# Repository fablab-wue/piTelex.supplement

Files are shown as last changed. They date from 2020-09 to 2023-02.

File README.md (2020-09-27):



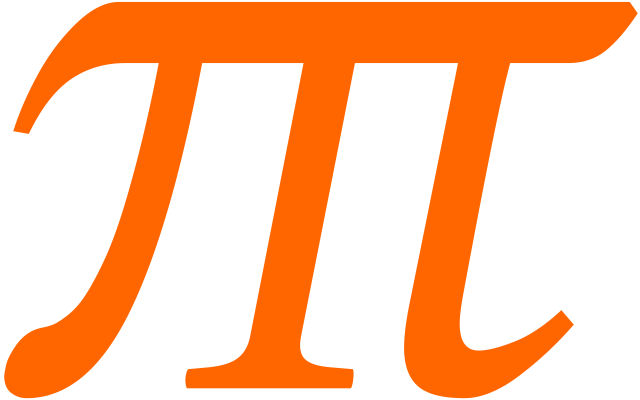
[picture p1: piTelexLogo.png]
# - piTelex.supplement



This project hold the additional files for the teletype project [piTelex](https://github.com/fablab-wue/piTelex)

**[For more informations see the WIKI pages](https://github.com/fablab-wue/piTelex/wiki)**

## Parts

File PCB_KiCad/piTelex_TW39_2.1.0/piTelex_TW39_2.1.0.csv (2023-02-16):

Source: | C:\KiCad\yyy\yyy.kicad_sch
Date: | 13/12/2022 18:44:19
Tool: | Eeschema (6.0.9)
Generator: | C:\Program Files\KiCad\6.0\bin\scripting\plugins/bom_csv_grouped_by_value.py
Component Count: | 58
Individual Components:
Item | Qty | Reference(s) | Value | LibPart | Footprint | Datasheet
 |  | C1 | 100n | Device:C | Capacitor_SMD:C_0805_2012Metric_Pad1.18x1.45mm_HandSolder | ~
 |  | C2 | 100n | Device:C | Capacitor_SMD:C_0805_2012Metric_Pad1.18x1.45mm_HandSolder | ~
 |  | C3 | * | Device:C | Capacitor_THT:C_Rect_L9.0mm_W4.2mm_P7.50mm_MKT | ~
 |  | C4 | 100n X2 275...305V~ | Device:C | Capacitor_THT:C_Rect_L16.5mm_W6.0mm_P15.00mm_MKT | ~
 |  | C5 | 100n | Device:C | Capacitor_SMD:C_0805_2012Metric_Pad1.18x1.45mm_HandSolder | ~
 |  | C6 | 100n | Device:C | Capacitor_SMD:C_0805_2012Metric_Pad1.18x1.45mm_HandSolder | ~
 |  | C7 | 100n | Device:C | Capacitor_SMD:C_0805_2012Metric_Pad1.18x1.45mm_HandSolder | ~
 |  | C8 | C_Polarized | Device:C_Polarized | Capacitor_Tantalum_SMD:CP_EIA-7343-31_Kemet-D_Pad2.25x2.55mm_HandSolder | ~
 |  | C9 | 100n | Device:C | Capacitor_SMD:C_0805_2012Metric_Pad1.18x1.45mm_HandSolder | ~
 |  | C10 | 100n | Device:C | Capacitor_SMD:C_0805_2012Metric_Pad1.18x1.45mm_HandSolder | ~
 |  | C11 | 100n | Device:C | Capacitor_SMD:C_0805_2012Metric_Pad1.18x1.45mm_HandSolder | ~
 |  | C12 | 100n | Device:C | Capacitor_SMD:C_0805_2012Metric_Pad1.18x1.45mm_HandSolder | ~
 |  | C13 | 100n | Device:C | Capacitor_SMD:C_0805_2012Metric_Pad1.18x1.45mm_HandSolder | ~
 |  | D1 | B250C1500G | Diode_Bridge:B250C1500G | Diode_THT:Diode_Bridge_Round_D9.8mm | https://www.vishay.com/docs/88501/b40c1500g.pdf
 |  | D2 | 1N4007 | Diode:1N4007 | Diode_THT:D_T-1_P2.54mm_Vertical_KathodeUp | http://www.vishay.com/docs/88503/1n4001.pdf
 |  | D3 | 1N4007 | Diode:1N4007 | Diode_THT:D_T-1_P2.54mm_Vertical_KathodeUp | http://www.vishay.com/docs/88503/1n4001.pdf
 |  | H1 | MountingHole_Pad | Mechanical:MountingHole_Pad | MountingHole:MountingHole_2.7mm_M2.5_ISO7380_Pad | ~
 |  | H2 | MountingHole_Pad | Mechanical:MountingHole_Pad | MountingHole:MountingHole_2.7mm_M2.5_ISO7380_Pad | ~
 |  | H3 | MountingHole_Pad | Mechanical:MountingHole_Pad | MountingHole:MountingHole_2.7mm_M2.5_ISO7380_Pad | ~
 |  | H4 | MountingHole_Pad | Mechanical:MountingHole_Pad | MountingHole:MountingHole_2.7mm_M2.5_ISO7380_Pad | ~
 |  | J1 | Screw_Terminal_01x02 | Connector:Screw_Terminal_01x02 | Connector_Molex:Molex_KK-254_AE-6410-02A_1x02_P2.54mm_Vertical | ~
 |  | J2 | Screw_Terminal_01x02 | Connector:Screw_Terminal_01x02 | Connector_Molex:Molex_KK-254_AE-6410-02A_1x02_P2.54mm_Vertical | ~
 |  | J3 | Raspberry_Pi_2_3 | Connector:Raspberry_Pi_2_3 | Connector_PinHeader_2.54mm:PinHeader_2x20_P2.54mm_Vertical | https://www.raspberrypi.org/documentation/hardware/raspberrypi/schematics/rpi_SCH_3bplus_1p0_reduced.pdf
 |  | J4 | Screw_Terminal_01x04 | Connector:Screw_Terminal_01x04 | Connector_Molex:Molex_KK-254_AE-6410-04A_1x04_P2.54mm_Vertical | ~
 |  | J5 | Screw_Terminal_01x02 | Connector:Screw_Terminal_01x02 | Connector_Molex:Molex_KK-254_AE-6410-02A_1x02_P2.54mm_Vertical | ~
 |  | J6 | Screw_Terminal_01x03 | Connector:Screw_Terminal_01x03 | Connector_Molex:Molex_KK-254_AE-6410-03A_1x03_P2.54mm_Vertical | ~
 |  | J7 | Screw_Terminal_01x05 | Connector:Screw_Terminal_01x05 | Connector_Molex:Molex_KK-254_AE-6410-05A_1x05_P2.54mm_Vertical | ~
 |  | J8 | Screw_Terminal_01x03 | Connector:Screw_Terminal_01x03 | Connector_Molex:Molex_KK-254_AE-6410-03A_1x03_P2.54mm_Vertical | ~
 |  | J9 | Screw_Terminal_01x02 | Connector:Screw_Terminal_01x02 | Connector_Molex:Molex_KK-254_AE-6410-02A_1x02_P2.54mm_Vertical | ~
 |  | J10 | Screw_Terminal_01x05 | Connector:Screw_Terminal_01x05 | Connector_Molex:Molex_KK-254_AE-6410-05A_1x05_P2.54mm_Vertical | ~
 |  | J11 | Screw_Terminal_01x04 | Connector:Screw_Terminal_01x04 | Connector_Molex:Molex_KK-254_AE-6410-04A_1x04_P2.54mm_Vertical | ~
 |  | J12 | Conn_01x03_Male | Connector:Conn_01x03_Male | Connector_PinHeader_2.54mm:PinHeader_1x03_P2.54mm_Vertical | ~
 |  | Q1 | BC338 | Transistor_BJT:BC338 | Package_TO_SOT_THT:TO-92_Inline | http://diotec.com/tl_files/diotec/files/pdf/datasheets/bc337
 |  | Q2 | BC338 | Transistor_BJT:BC338 | Package_TO_SOT_THT:TO-92_Inline | http://diotec.com/tl_files/diotec/files/pdf/datasheets/bc337
 |  | R1 | 68R | Device:R | Resistor_SMD:R_0805_2012Metric_Pad1.20x1.40mm_HandSolder | ~
 |  | R2 | 68R | Device:R | Resistor_SMD:R_0805_2012Metric_Pad1.20x1.40mm_HandSolder | ~
 |  | R3 | 330 | Device:R | Resistor_SMD:R_0805_2012Metric_Pad1.20x1.40mm_HandSolder | ~
 |  | R4 | 330 | Device:R | Resistor_SMD:R_0805_2012Metric_Pad1.20x1.40mm_HandSolder | ~
 |  | R5 | 330 | Device:R | Resistor_SMD:R_0805_2012Metric_Pad1.20x1.40mm_HandSolder | ~
 |  | R6 | 330 | Device:R | Resistor_SMD:R_0805_2012Metric_Pad1.20x1.40mm_HandSolder | ~
 |  | R7 | 330 | Device:R | Resistor_SMD:R_0805_2012Metric_Pad1.20x1.40mm_HandSolder | ~
 |  | R8 | 330 | Device:R | Resistor_SMD:R_0805_2012Metric_Pad1.20x1.40mm_HandSolder | ~
 |  | R9 | 1k | Device:R | Resistor_SMD:R_0805_2012Metric_Pad1.20x1.40mm_HandSolder | ~
 |  | R10 | 1k | Device:R | Resistor_SMD:R_0805_2012Metric_Pad1.20x1.40mm_HandSolder | ~
 |  | R11 | 1k | Device:R | Resistor_SMD:R_0805_2012Metric_Pad1.20x1.40mm_HandSolder | ~
 |  | R12 | 1k | Device:R | Resistor_SMD:R_0805_2012Metric_Pad1.20x1.40mm_HandSolder | ~
 |  | R13 | 3K3 | Device:R | Resistor_SMD:R_0805_2012Metric_Pad1.20x1.40mm_HandSolder | ~
 |  | R14 | 3K3 | Device:R | Resistor_SMD:R_0805_2012Metric_Pad1.20x1.40mm_HandSolder | ~
 |  | R15 | 3K3 | Device:R | Resistor_SMD:R_0805_2012Metric_Pad1.20x1.40mm_HandSolder | ~
 |  | R16 | 3K3 | Device:R | Resistor_SMD:R_0805_2012Metric_Pad1.20x1.40mm_HandSolder | ~
 |  | R17 | 3K3 | Device:R | Resistor_SMD:R_0805_2012Metric_Pad1.20x1.40mm_HandSolder | ~
 |  | R18 | 3K3 | Device:R | Resistor_SMD:R_0805_2012Metric_Pad1.20x1.40mm_HandSolder | ~
 |  | U1 | PC817 | Isolator:PC817 | Package_DIP:DIP-4_W7.62mm | http://www.soselectronic.cz/a_info/resource/d/pc817.pdf
 |  | U2 | TLP627 | Isolator:TLP627 | Package_DIP:DIP-4_W7.62mm | https://toshiba.semicon-storage.com/info/docget.jsp?did=16914&prodName=TLP627
 |  | U3 | TLP627 | Isolator:TLP627 | Package_DIP:DIP-4_W7.62mm | https://toshiba.semicon-storage.com/info/docget.jsp?did=16914&prodName=TLP627
 |  | U4 | TLP627 | Isolator:TLP627 | Package_DIP:DIP-4_W7.62mm | https://toshiba.semicon-storage.com/info/docget.jsp?did=16914&prodName=TLP627
 |  | U5 | TLP627 | Isolator:TLP627 | Package_DIP:DIP-4_W7.62mm | https://toshiba.semicon-storage.com/info/docget.jsp?did=16914&prodName=TLP627
 |  | U6 | R-78C5.0-1.0 | Regulator_Switching:R-78C5.0-1.0 | Converter_DCDC:Converter_DCDC_RECOM_R-78E-0.5_THT | https://www.recom-power.com/pdf/Innoline/R-78Cxx-1.0.pdf
Collated Components:
Item | Qty | Reference(s) | Value | LibPart | Footprint | Datasheet
1 | 10 | C1, C2, C5, C6, C7, C9, C10, C11, C12, C13 | 100n | Device:C | Capacitor_SMD:C_0805_2012Metric_Pad1.18x1.45mm_HandSolder | ~
2 | 1 | C3 | * | Device:C | Capacitor_THT:C_Rect_L9.0mm_W4.2mm_P7.50mm_MKT | ~
3 | 1 | C4 | 100n X2 275...305V~ | Device:C | Capacitor_THT:C_Rect_L16.5mm_W6.0mm_P15.00mm_MKT | ~
4 | 1 | C8 | C_Polarized | Device:C_Polarized | Capacitor_Tantalum_SMD:CP_EIA-7343-31_Kemet-D_Pad2.25x2.55mm_HandSolder | ~
5 | 1 | D1 | B250C1500G | Diode_Bridge:B250C1500G | Diode_THT:Diode_Bridge_Round_D9.8mm | https://www.vishay.com/docs/88501/b40c1500g.pdf
6 | 2 | D2, D3 | 1N4007 | Diode:1N4007 | Diode_THT:D_T-1_P2.54mm_Vertical_KathodeUp | http://www.vishay.com/docs/88503/1n4001.pdf
7 | 4 | H1, H2, H3, H4 | MountingHole_Pad | Mechanical:MountingHole_Pad | MountingHole:MountingHole_2.7mm_M2.5_ISO7380_Pad | ~
8 | 4 | J1, J2, J5, J9 | Screw_Terminal_01x02 | Connector:Screw_Terminal_01x02 | Connector_Molex:Molex_KK-254_AE-6410-02A_1x02_P2.54mm_Vertical | ~
9 | 1 | J3 | Raspberry_Pi_2_3 | Connector:Raspberry_Pi_2_3 | Connector_PinHeader_2.54mm:PinHeader_2x20_P2.54mm_Vertical | https://www.raspberrypi.org/documentation/hardware/raspberrypi/schematics/rpi_SCH_3bplus_1p0_reduced.pdf
10 | 2 | J4, J11 | Screw_Terminal_01x04 | Connector:Screw_Terminal_01x04 | Connector_Molex:Molex_KK-254_AE-6410-04A_1x04_P2.54mm_Vertical | ~
11 | 2 | J6, J8 | Screw_Terminal_01x03 | Connector:Screw_Terminal_01x03 | Connector_Molex:Molex_KK-254_AE-6410-03A_1x03_P2.54mm_Vertical | ~
12 | 2 | J7, J10 | Screw_Terminal_01x05 | Connector:Screw_Terminal_01x05 | Connector_Molex:Molex_KK-254_AE-6410-05A_1x05_P2.54mm_Vertical | ~
13 | 1 | J12 | Conn_01x03_Male | Connector:Conn_01x03_Male | Connector_PinHeader_2.54mm:PinHeader_1x03_P2.54mm_Vertical | ~
14 | 2 | Q1, Q2 | BC338 | Transistor_BJT:BC338 | Package_TO_SOT_THT:TO-92_Inline | http://diotec.com/tl_files/diotec/files/pdf/datasheets/bc337
15 | 2 | R1, R2 | 68R | Device:R | Resistor_SMD:R_0805_2012Metric_Pad1.20x1.40mm_HandSolder | ~
16 | 6 | R3, R4, R5, R6, R7, R8 | 330 | Device:R | Resistor_SMD:R_0805_2012Metric_Pad1.20x1.40mm_HandSolder | ~
17 | 4 | R9, R10, R11, R12 | 1k | Device:R | Resistor_SMD:R_0805_2012Metric_Pad1.20x1.40mm_HandSolder | ~
18 | 6 | R13, R14, R15, R16, R17, R18 | 3K3 | Device:R | Resistor_SMD:R_0805_2012Metric_Pad1.20x1.40mm_HandSolder | ~
19 | 1 | U1 | PC817 | Isolator:PC817 | Package_DIP:DIP-4_W7.62mm | http://www.soselectronic.cz/a_info/resource/d/pc817.pdf
20 | 4 | U2, U3, U4, U5 | TLP627 | Isolator:TLP627 | Package_DIP:DIP-4_W7.62mm | https://toshiba.semicon-storage.com/info/docget.jsp?did=16914&prodName=TLP627
21 | 1 | U6 | R-78C5.0-1.0 | Regulator_Switching:R-78C5.0-1.0 | Converter_DCDC:Converter_DCDC_RECOM_R-78E-0.5_THT | https://www.recom-power.com/pdf/Innoline/R-78Cxx-1.0.pdf

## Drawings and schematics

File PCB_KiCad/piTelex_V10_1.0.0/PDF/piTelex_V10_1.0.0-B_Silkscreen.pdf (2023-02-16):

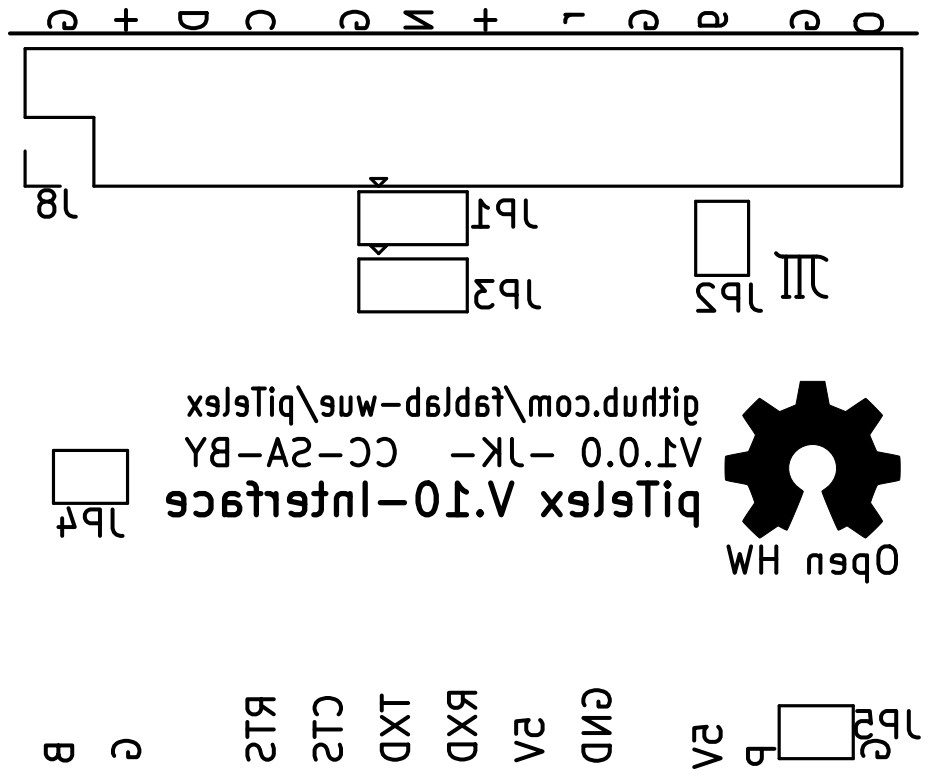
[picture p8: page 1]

G5V CC-SA-BY GNDG

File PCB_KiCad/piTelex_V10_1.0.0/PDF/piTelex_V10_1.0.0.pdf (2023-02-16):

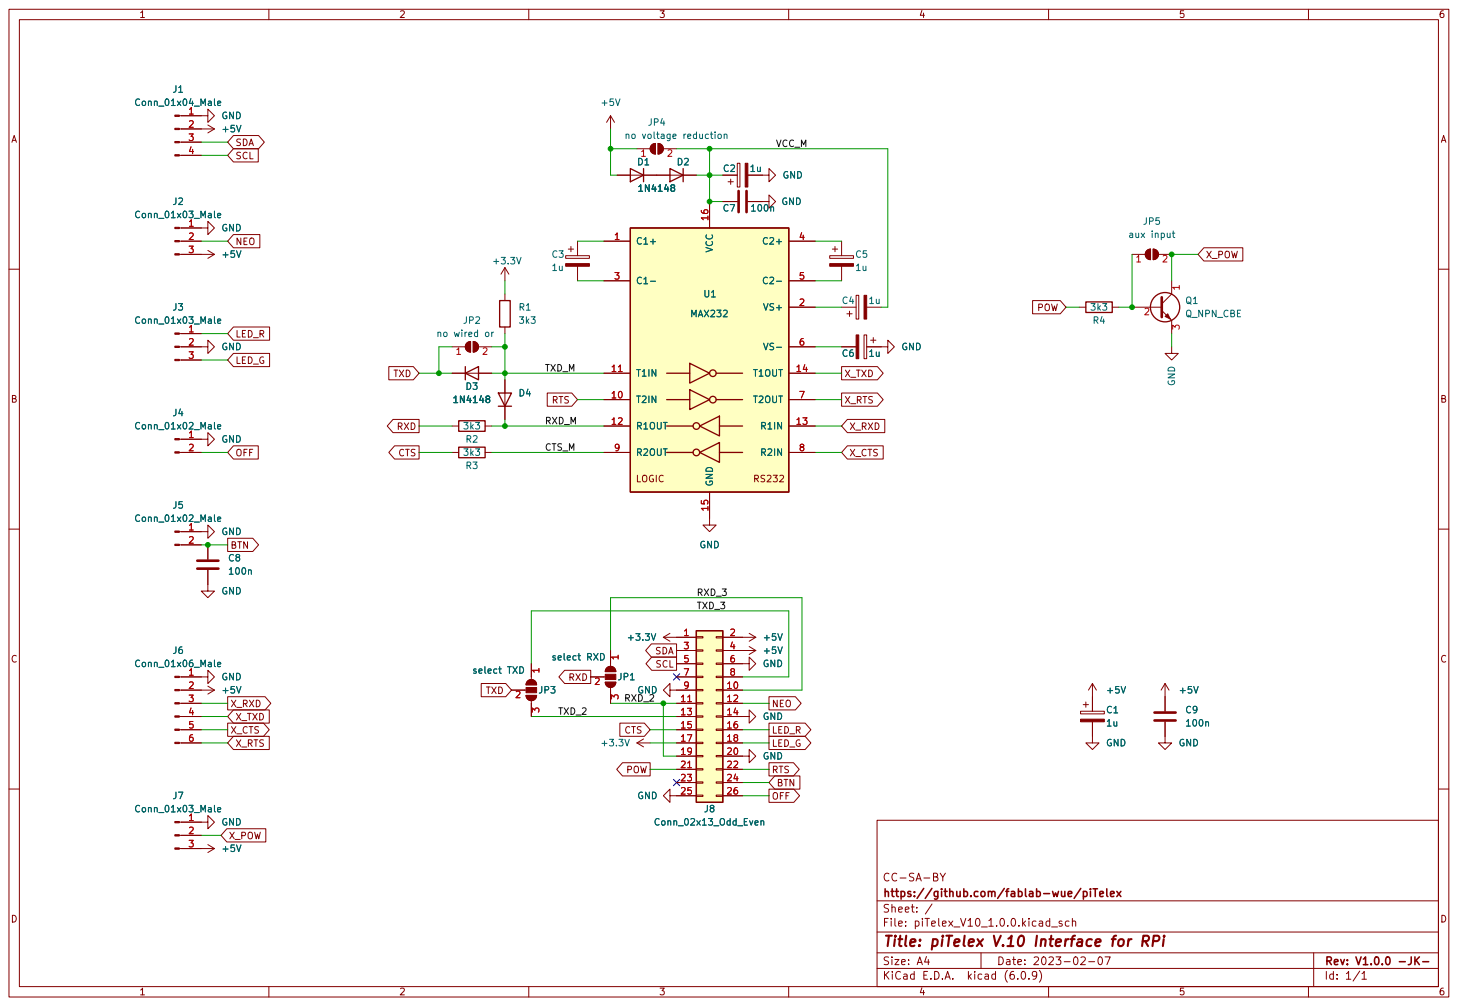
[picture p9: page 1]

aux input GND GND 1234

File: piTelex_V10_1.0.0.kicad_sch Sheet: / https://github.com/fablab-wue/piTelex CC-SA-BY

Id: 1/1 Title: piTelex V.10 Interface for RPi

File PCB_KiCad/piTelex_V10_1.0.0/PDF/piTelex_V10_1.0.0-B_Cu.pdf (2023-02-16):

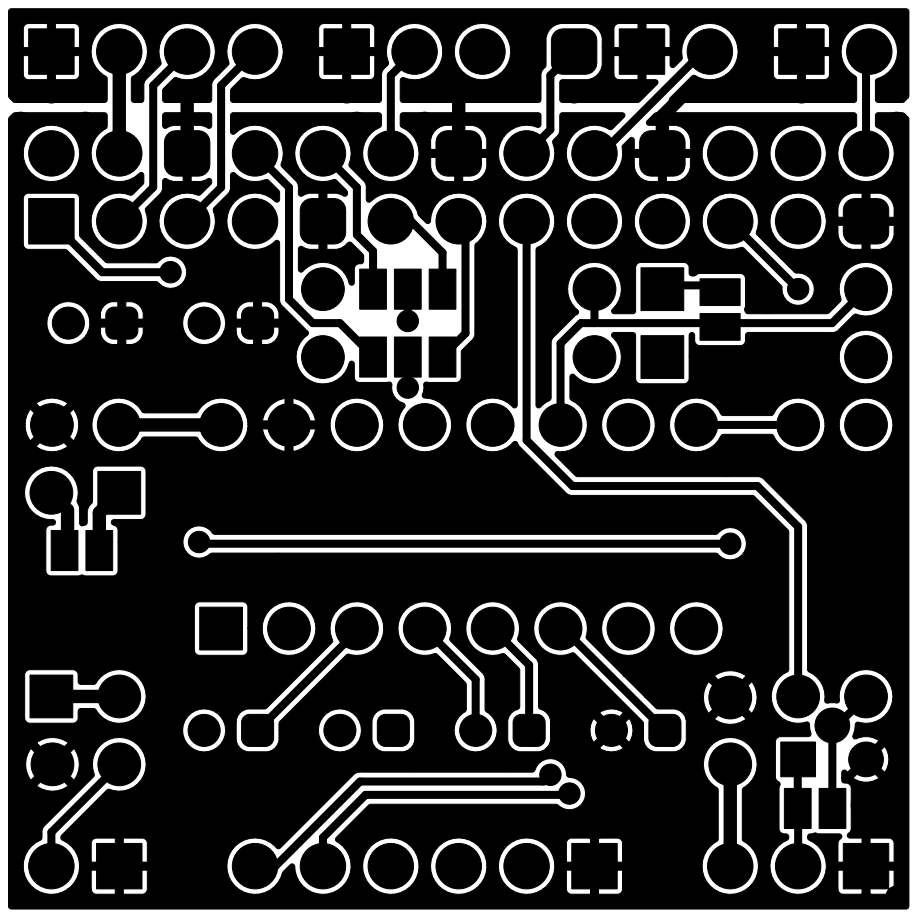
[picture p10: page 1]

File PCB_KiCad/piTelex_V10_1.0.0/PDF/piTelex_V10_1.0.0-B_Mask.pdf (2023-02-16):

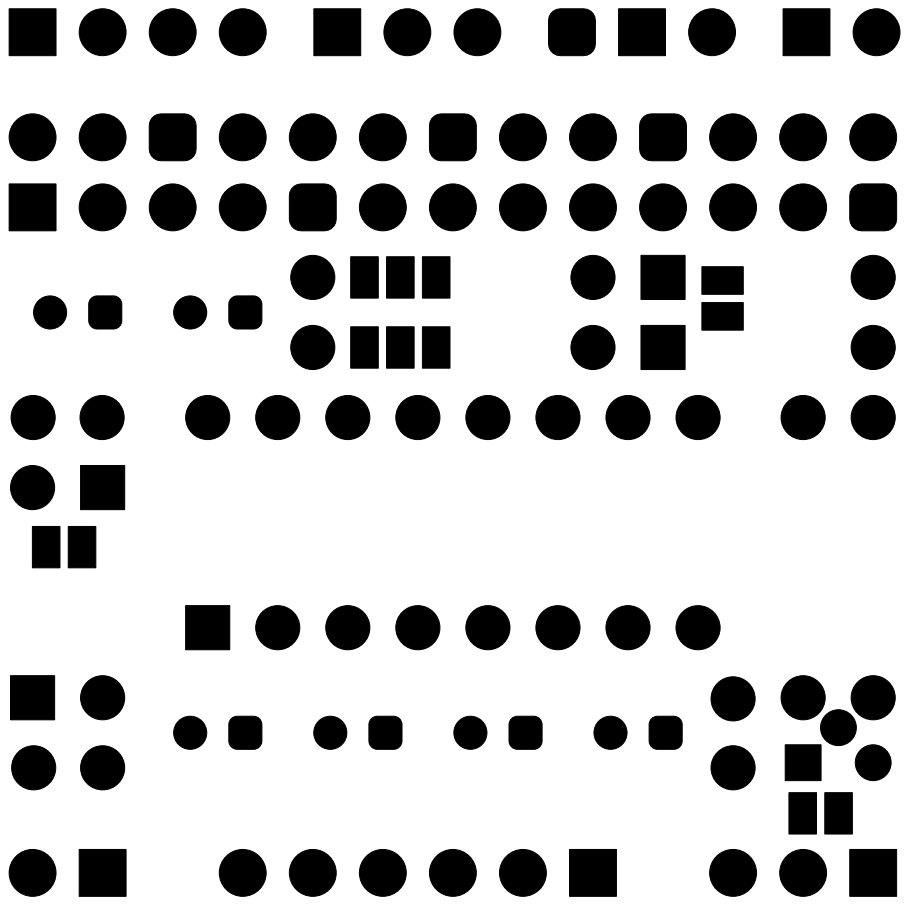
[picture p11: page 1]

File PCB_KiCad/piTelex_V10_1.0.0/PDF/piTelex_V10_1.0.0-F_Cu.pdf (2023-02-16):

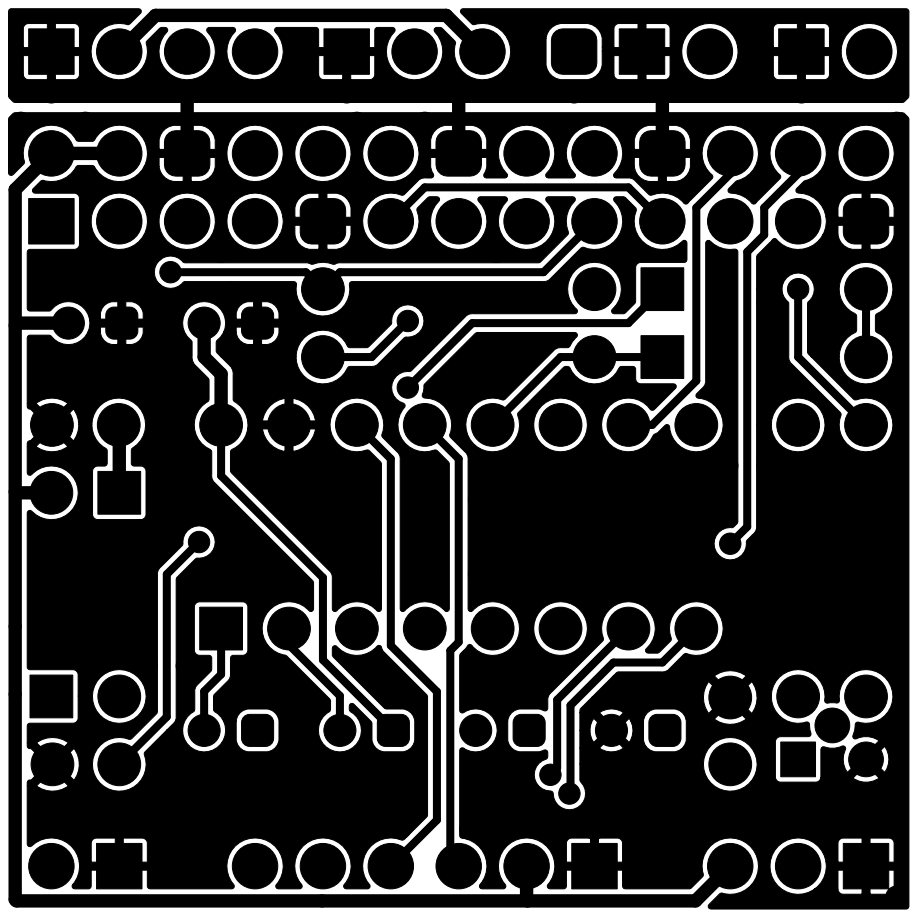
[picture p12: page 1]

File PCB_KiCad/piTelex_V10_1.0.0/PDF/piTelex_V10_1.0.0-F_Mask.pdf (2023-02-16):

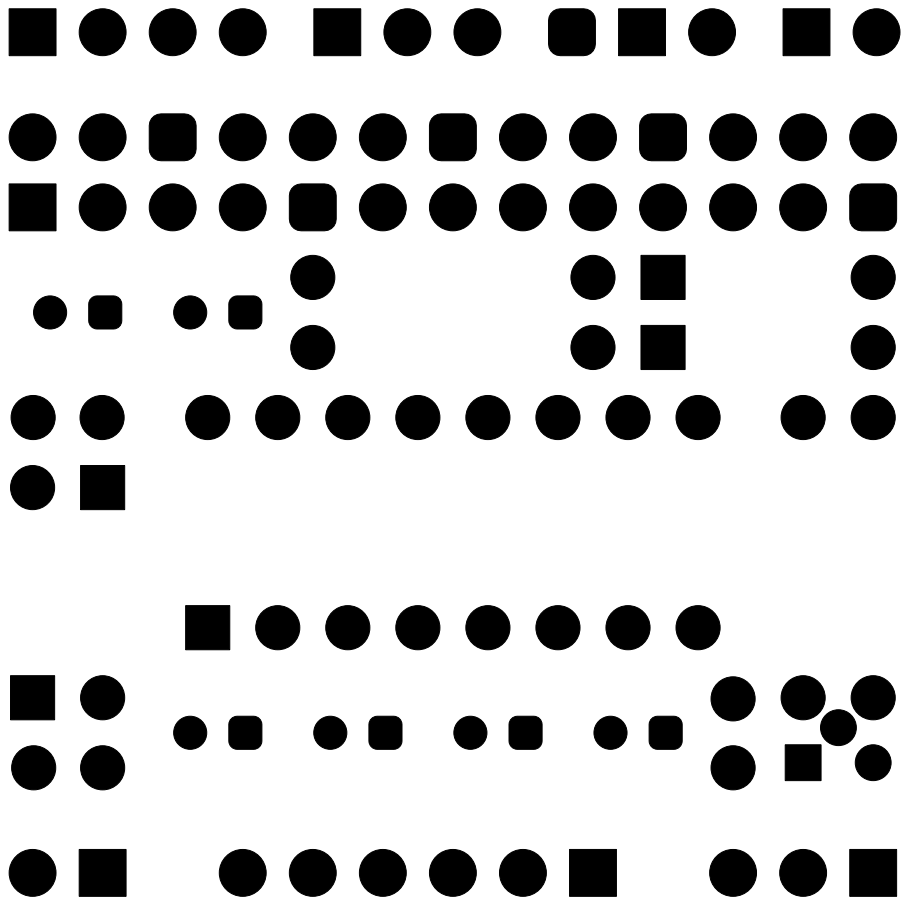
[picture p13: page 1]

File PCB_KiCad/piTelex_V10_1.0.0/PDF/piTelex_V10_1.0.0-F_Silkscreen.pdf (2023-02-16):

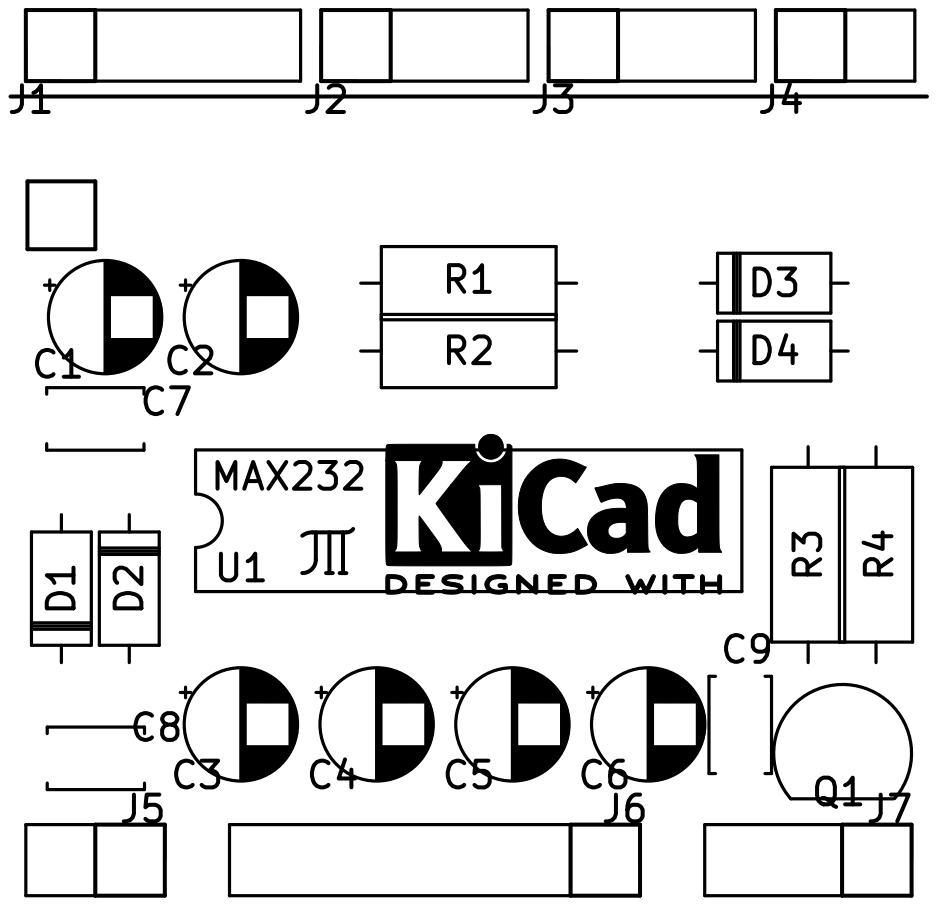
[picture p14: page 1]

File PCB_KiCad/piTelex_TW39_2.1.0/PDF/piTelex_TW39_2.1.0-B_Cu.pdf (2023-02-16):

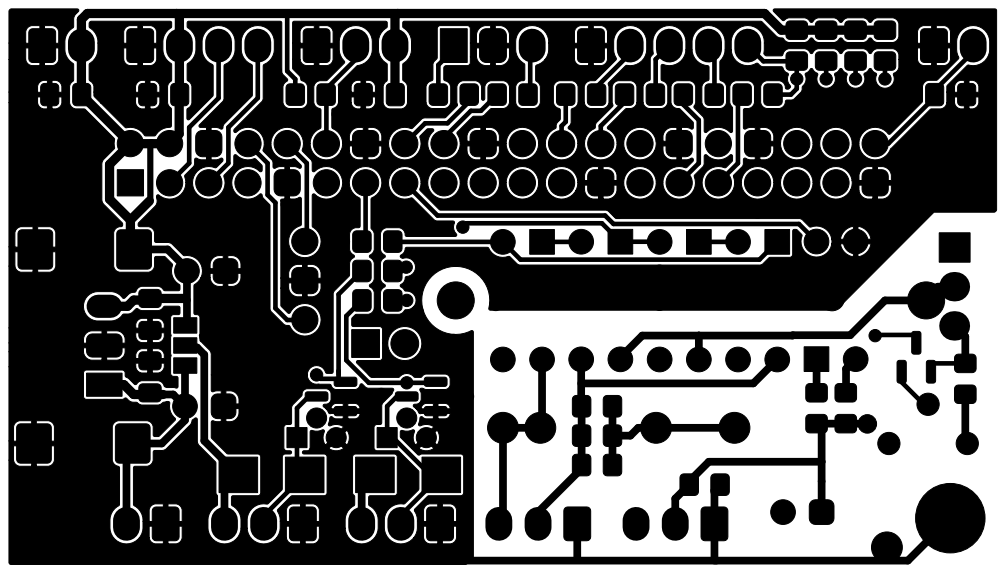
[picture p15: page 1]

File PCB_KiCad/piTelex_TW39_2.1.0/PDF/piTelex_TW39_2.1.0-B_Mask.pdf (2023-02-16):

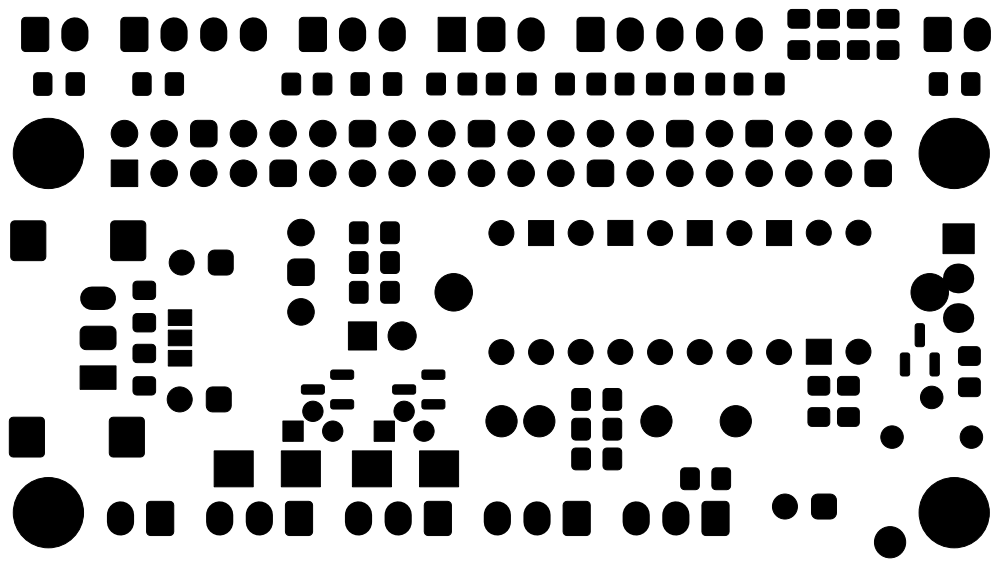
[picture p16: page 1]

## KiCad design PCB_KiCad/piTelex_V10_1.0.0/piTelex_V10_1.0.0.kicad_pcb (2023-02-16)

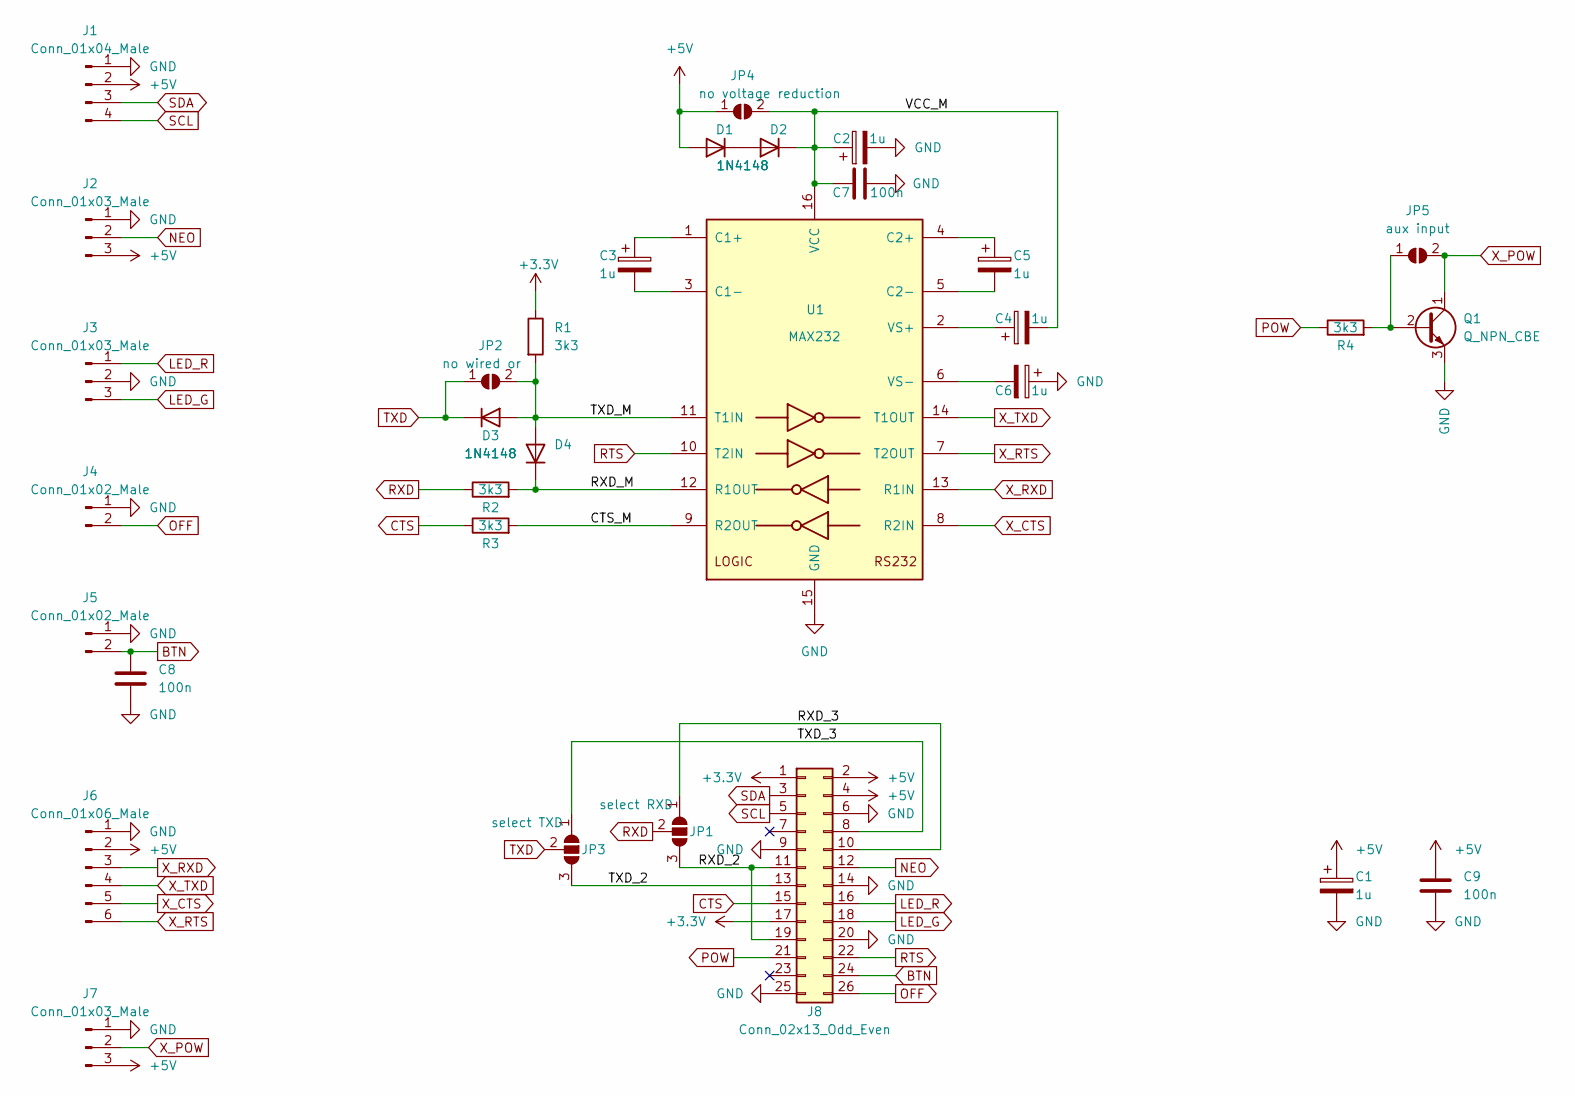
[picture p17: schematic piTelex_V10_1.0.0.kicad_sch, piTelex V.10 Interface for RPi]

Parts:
C1, C2, C3, C4, C5, C6: 1u; CP_Radial_D4.0mm_P2.00mm
C7, C8, C9: 100n; C_Disc_D3.4mm_W2.1mm_P2.50mm
D1, D2, D3, D4: 1N4148; D_DO-35_SOD27_P7.62mm_Horizontal
J1: Conn_01x04_Male; PinHeader_1x04_P2.54mm_Vertical
J2, J3, J7: Conn_01x03_Male; PinHeader_1x03_P2.54mm_Vertical
J4, J5: Conn_01x02_Male; PinHeader_1x02_P2.54mm_Vertical
J6: Conn_01x06_Male; PinHeader_1x06_P2.54mm_Vertical
J8: Conn_02x13_Odd_Even; PinSocket_2x13_P2.54mm_Vertical
JP1: select RXD; SolderJumper-3_P1.3mm_Open_Pad1.0x1.5mm
JP2: no wired or; SolderJumper-2_P1.3mm_Open_Pad1.0x1.5mm
JP3: select TXD; SolderJumper-3_P1.3mm_Open_Pad1.0x1.5mm
JP4: no voltage reduction; SolderJumper-2_P1.3mm_Open_Pad1.0x1.5mm
JP5: aux input; SolderJumper-2_P1.3mm_Open_Pad1.0x1.5mm
Q1: Q_NPN_CBE; TO-92L
R1, R2, R3, R4: 3k3; R_Axial_DIN0207_L6.3mm_D2.5mm_P10.16mm_Horizontal
U1: MAX232; DIP-16_W7.62mm

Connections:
+3.3V: J8.1, J8.17, R1.1
+5V: C1.1, C9.1, D1.2 (A), J1.2, J2.3, J6.2, J7.3, J8.2, J8.4, JP4.1 (A)
/CTS_M: R3.2, U1.9 (R2OUT)
/RXD_2: J8.11, J8.19, JP1.3 (B)
/RXD_3: J8.10, JP1.1 (A)
/RXD_M: D4.1 (K), R2.2, U1.12 (R1OUT)
/TXD_2: J8.13, JP3.3 (B)
/TXD_3: J8.8, JP3.1 (A)
/TXD_M: D3.2 (A), D4.2 (A), JP2.2 (B), R1.2, U1.11 (T1IN)
/VCC_M: C2.1, C4.2, C7.1, D2.1 (K), JP4.2 (B), U1.16 (VCC)
BTN: C8.1, J5.2, J8.24
CTS: J8.15, R3.1
GND: C1.2, C2.2, C6.1, C7.2, C8.2, C9.2, J1.1, J2.1, J3.2, J4.1, J5.1, J6.1, J7.1, J8.6, J8.9, J8.14, J8.20, J8.25, Q1.3 (E), U1.15 (GND)
LED_G: J3.3, J8.18
LED_R: J3.1, J8.16
NEO: J2.2, J8.12
unnamed: C3.1, U1.1 (C1+)
unnamed: C3.2, U1.3 (C1-)
unnamed: C4.1, U1.2 (VS+)
unnamed: C5.1, U1.4 (C2+)
unnamed: C5.2, U1.5 (C2-)
unnamed: C6.2, U1.6 (VS-)
unnamed: D1.1 (K), D2.2 (A)
unnamed: JP5.1 (A), Q1.2 (B), R4.2
OFF: J4.2, J8.26
POW: J8.21, R4.1
RTS: J8.22, U1.10 (T2IN)
RXD: JP1.2 (C), R2.1
SCL: J1.4, J8.5
SDA: J1.3, J8.3
TXD: D3.1 (K), JP2.1 (A), JP3.2 (C)
X_CTS: J6.5, U1.8 (R2IN)
X_POW: J7.2, JP5.2 (B), Q1.1 (C)
X_RTS: J6.6, U1.7 (T2OUT)
X_RXD: J6.3, U1.13 (R1IN)
X_TXD: J6.4, U1.14 (T1OUT)

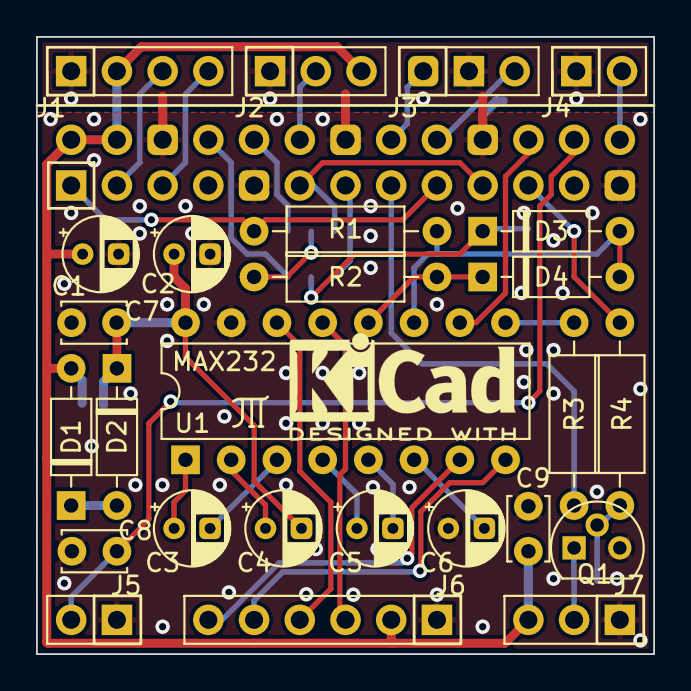
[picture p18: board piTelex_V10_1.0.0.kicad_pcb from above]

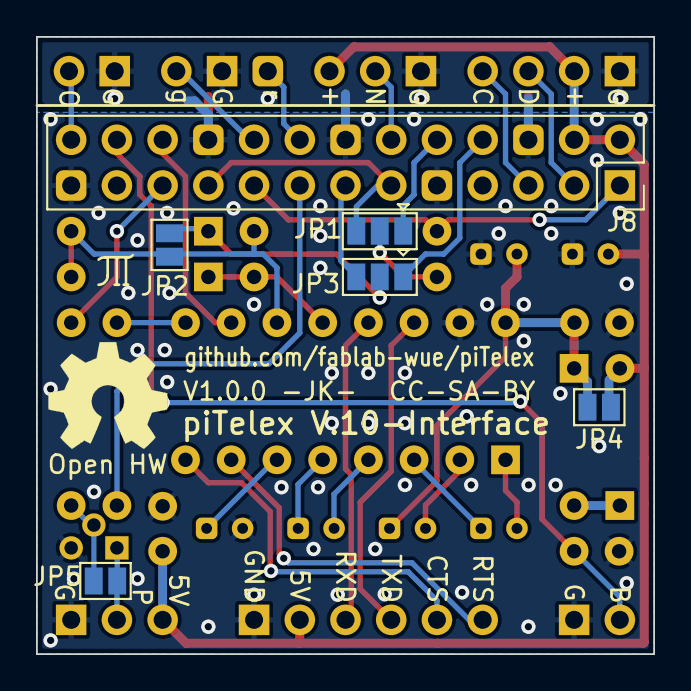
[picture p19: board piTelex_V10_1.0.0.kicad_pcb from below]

Board: 2 copper layers, 34.3 x 34.3 mm, 32 parts (6 on the bottom side), 36 nets.

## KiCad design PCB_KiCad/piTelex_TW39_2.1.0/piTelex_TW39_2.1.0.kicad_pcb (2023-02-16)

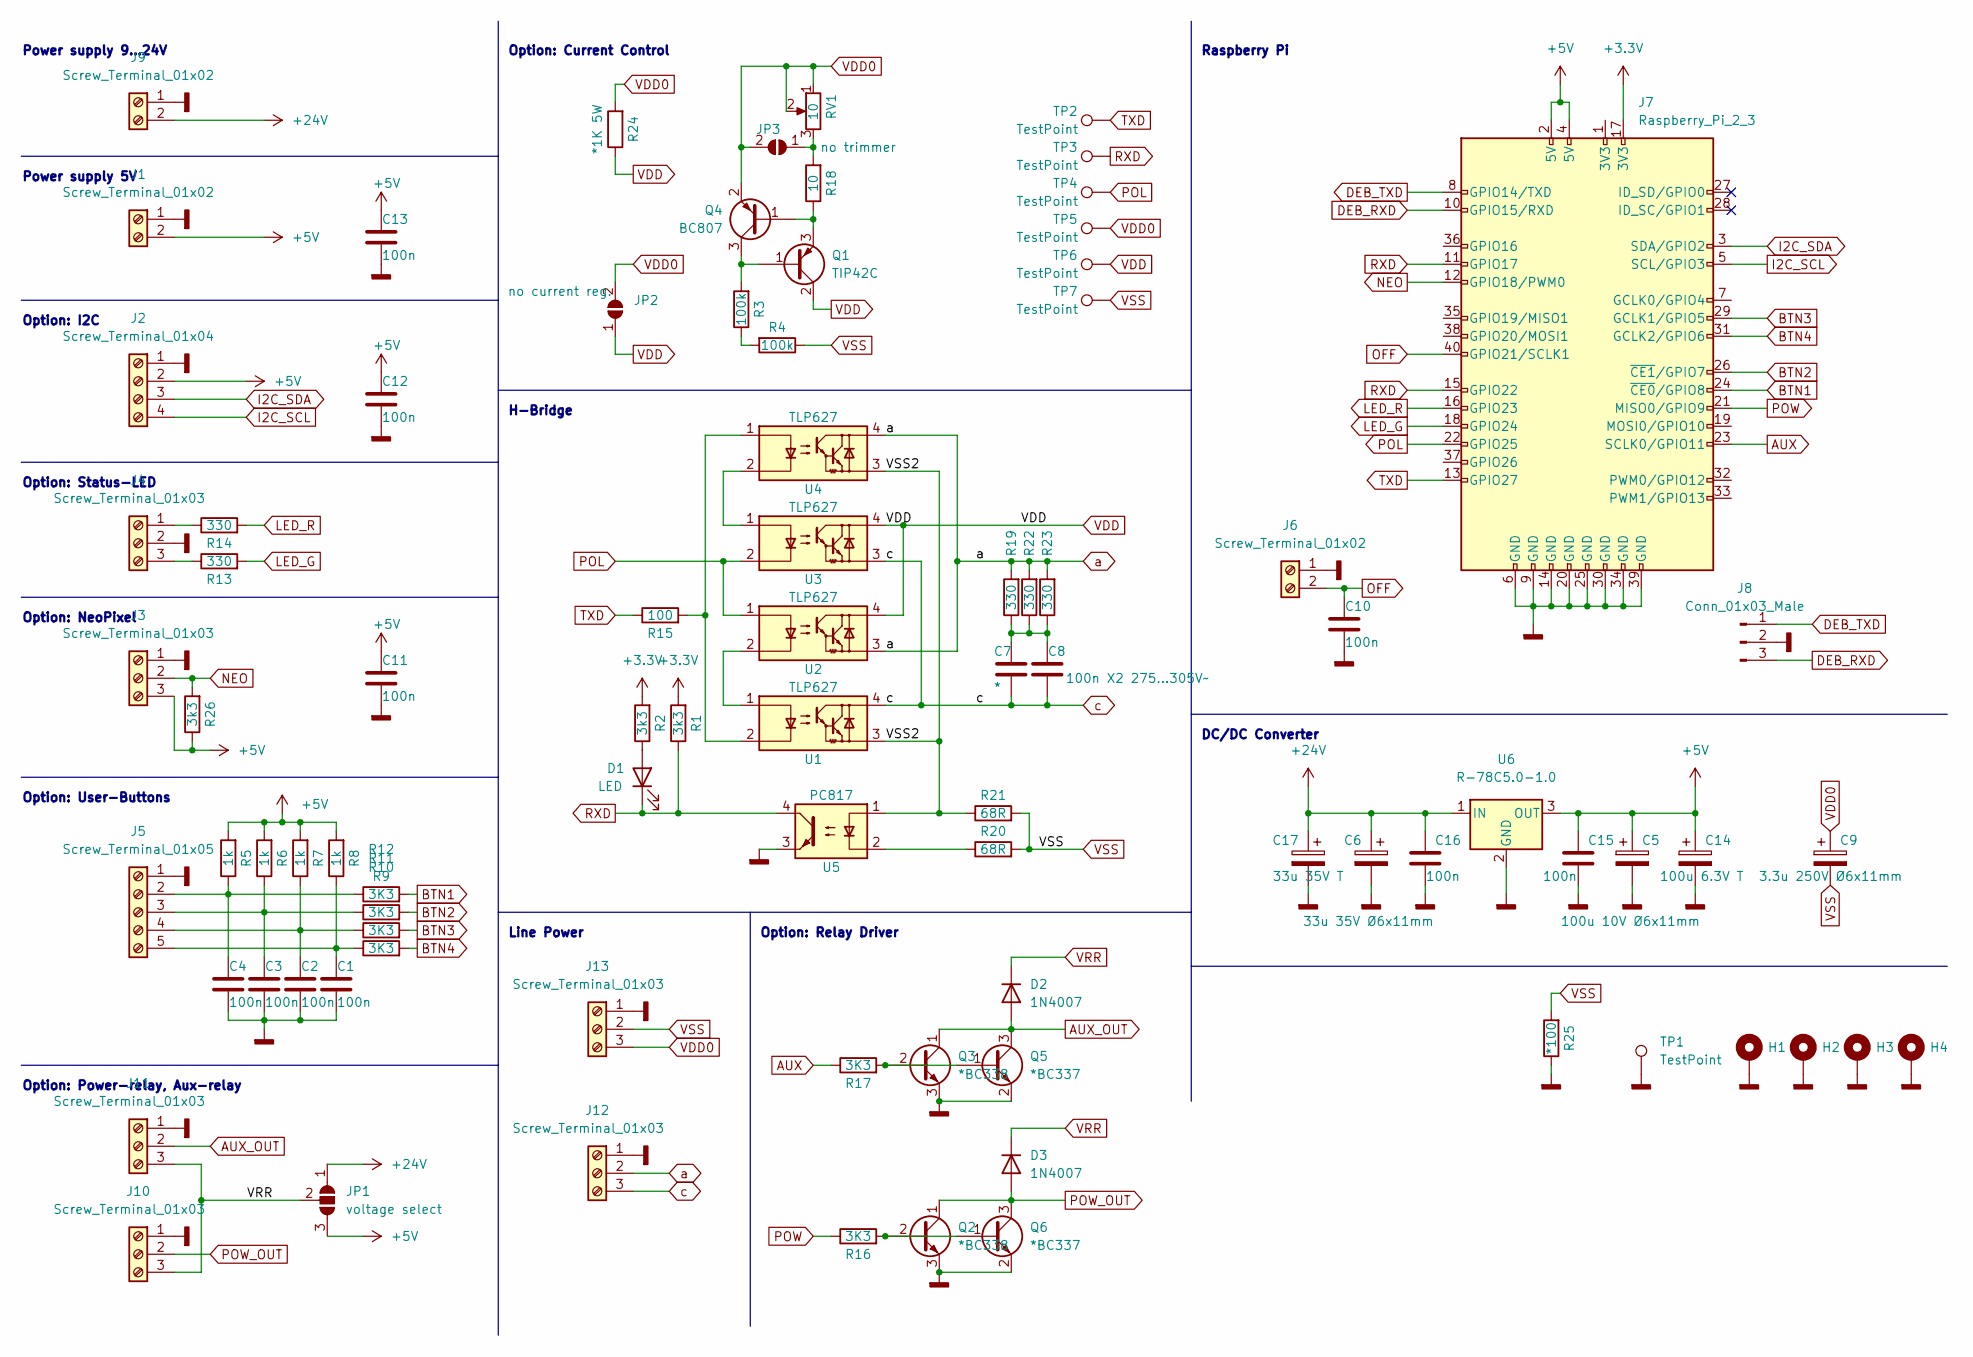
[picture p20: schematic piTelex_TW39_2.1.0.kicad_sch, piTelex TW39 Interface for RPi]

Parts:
C1, C2, C3, C4, C10, C11, C12, C13, C15, C16: 100n; C_0805_2012Metric_Pad1.18x1.45mm_HandSolder
C5: 100u 10V Ø6x11mm; CP_Radial_D7.5mm_P2.50mm
C6: 33u 35V Ø6x11mm; CP_Radial_D7.5mm_P2.50mm
C7: *; C_Rect_L9.0mm_W4.2mm_P7.50mm_MKT
C8: 100n X2 275...305V~; C_Rect_L16.5mm_W6.0mm_P15.00mm_MKT
C9: 3.3u 250V Ø6x11mm; CP_Radial_D7.5mm_P2.50mm
C14: 100u 6.3V T; CP_EIA-7343-31_Kemet-D_Pad2.25x2.55mm_HandSolder
C17: 33u 35V T; CP_EIA-7343-31_Kemet-D_Pad2.25x2.55mm_HandSolder
D1: LED; LED_D5.0mm
D2, D3: 1N4007; D_SMB
H1, H2, H3, H4: MountingHole_Pad; MountingHole_2.7mm_M2.5_ISO7380_Pad
J1, J6, J9: Screw_Terminal_01x02; Molex_KK-254_AE-6410-02A_1x02_P2.54mm_Vertical
J2: Screw_Terminal_01x04; Molex_KK-254_AE-6410-04A_1x04_P2.54mm_Vertical
J3, J4, J10, J11, J12, J13: Screw_Terminal_01x03; Molex_KK-254_AE-6410-03A_1x03_P2.54mm_Vertical
J5: Screw_Terminal_01x05; Molex_KK-254_AE-6410-05A_1x05_P2.54mm_Vertical
J7: Raspberry_Pi_2_3; PinSocket_2x20_P2.54mm_Vertical
J8: Conn_01x03_Male; PinHeader_1x03_P2.54mm_Vertical
JP1: voltage select; SolderJumper-3_P1.3mm_Open_Pad1.0x1.5mm
JP2: no current reg.; SolderJumper-2_P1.3mm_Open_Pad1.0x1.5mm
JP3: no trimmer; SolderJumper-2_P1.3mm_Open_Pad1.0x1.5mm
Q1: TIP42C; TO-220-3_Vertical
Q2, Q3: *BC338; TO-92
Q4: BC807; SOT-23
Q5, Q6: *BC337; SOT-23
R1, R2, R26: 3k3; R_0805_2012Metric_Pad1.20x1.40mm_HandSolder
R3, R4: 100k; R_0805_2012Metric_Pad1.20x1.40mm_HandSolder
R5, R6, R7, R8: 1k; R_0805_2012Metric_Pad1.20x1.40mm_HandSolder
R9, R10, R11, R12, R16, R17: 3K3; R_0805_2012Metric_Pad1.20x1.40mm_HandSolder
R13, R14, R19, R22, R23: 330; R_0805_2012Metric_Pad1.20x1.40mm_HandSolder
R15: 100; R_0805_2012Metric_Pad1.20x1.40mm_HandSolder
R18: 10; R_0805_2012Metric_Pad1.20x1.40mm_HandSolder
R20, R21: 68R; R_0805_2012Metric_Pad1.20x1.40mm_HandSolder
R24: *1K 5W; R_Axial_Power_L25.0mm_W9.0mm_P30.48mm
R25: *100; R_0805_2012Metric_Pad1.20x1.40mm_HandSolder
RV1: 10; Potentiometer_Bourns_3299Z_Horizontal
TP1: TestPoint; Pin_D1.0mm_L10.0mm
TP2, TP3, TP4, TP5, TP6, TP7: TestPoint; TestPoint_Pad_D1.5mm
U1, U2, U3, U4: TLP627; DIP-4_W7.62mm
U5: PC817; DIP-4_W7.62mm
U6: R-78C5.0-1.0; Converter_DCDC_RECOM_R-78E-0.5_THT

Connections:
+3.3V: J7.17 (3V3), R1.2, R2.2
+5V: C5.1, C11.1, C12.1, C13.1, C14.1, C15.1, J1.2, J2.2, J3.3, J7.2 (5V), J7.4 (5V), JP1.3 (B), R5.2, R6.2, R7.2, R8.2, R26.1, U6.3 (OUT)
+24V: C6.1, C16.1, C17.1, J9.2, JP1.1 (A), U6.1 (IN)
/VSS2: R21.1, U1.3, U4.3, U5.1
AUX: J7.23 (SCLK0/GPIO11), R17.1
AUX_OUT: D2.2 (A), J11.2, Q3.1 (C), Q5.3 (C)
BTN1: J7.24 (~CE0/GPIO8), R12.2
BTN2: J7.26 (~CE1/GPIO7), R11.2
BTN3: J7.29 (GCLK1/GPIO5), R10.2
BTN4: J7.31 (GCLK2/GPIO6), R9.2
DEB_RXD: J7.10 (GPIO15/RXD), J8.3
DEB_TXD: J7.8 (GPIO14/TXD), J8.1
GNDD: C1.2, C2.2, C3.2, C4.2, C5.2, C6.2, C10.2, C11.2, C12.2, C13.2, C14.2, C15.2, C16.2, C17.2, H1.1, H2.1, H3.1, H4.1, J1.1, J2.1, J3.1, J4.2, J5.1, J6.1, J7.6 (GND), J7.9 (GND), J7.14 (GND), J7.20 (GND), J7.25 (GND), J7.30 (GND), J7.34 (GND), J7.39 (GND), J8.2, J9.1, J10.1, J11.1, J12.1, J13.1, Q2.3 (E), Q3.3 (E), Q5.2 (E), Q6.2 (E), R25.1, TP1.1, U5.3, U6.2 (GND)
I2C_SCL: J2.4, J7.5 (SCL/GPIO3)
I2C_SDA: J2.3, J7.3 (SDA/GPIO2)
LED_G: J7.18 (GPIO24), R13.2
LED_R: J7.16 (GPIO23), R14.2
NEO: J3.2, J7.12 (GPIO18/PWM0), R26.2
unnamed: C1.1, J5.5, R8.1, R9.1
unnamed: C2.1, J5.4, R7.1, R10.1
unnamed: C3.1, J5.3, R6.1, R11.1
unnamed: C4.1, J5.2, R5.1, R12.1
unnamed: C7.1, C8.1, R19.1, R22.1, R23.1
unnamed: J4.1, R14.1
unnamed: J4.3, R13.1
unnamed: Q3.2 (B), Q5.1 (B), R17.2
unnamed: Q1.3 (E), Q4.1 (B), R18.1
unnamed: Q1.1 (B), Q4.3 (C), R3.2
unnamed: Q2.2 (B), Q6.1 (B), R16.2
unnamed: D1.2 (A), R2.1
unnamed: R3.1, R4.2
unnamed: JP3.1 (A), R18.2, RV1.3
unnamed: U1.1, U2.2
unnamed: R15.2, U1.2, U4.1
unnamed: U3.1, U4.2
unnamed: R20.1, U5.2
OFF: C10.1, J6.2, J7.40 (GPIO21/SCLK1)
POL: J7.22 (GPIO25), TP4.1, U2.1, U3.2
POW: J7.21 (MISO0/GPIO9), R16.1
POW_OUT: D3.2 (A), J10.2, Q2.1 (C), Q6.3 (C)
RXD: D1.1 (K), J7.11 (GPIO17), J7.15 (GPIO22), R1.1, TP3.1, U5.4
TXD: J7.13 (GPIO27), R15.1, TP2.1
VDD: JP2.1 (A), Q1.2 (C), R24.1, TP6.1, U2.4, U3.4
VDD0: C9.1, J13.3, JP2.2 (B), JP3.2 (B), Q4.2 (E), R24.2, RV1.1, RV1.2, TP5.1
VRR: D2.1 (K), D3.1 (K), J10.3, J11.3, JP1.2 (C)
VSS: C9.2, J13.2, R4.1, R20.2, R21.2, R25.2, TP7.1
a: J12.2, R19.2, R22.2, R23.2, U2.3, U4.4
c: C7.2, C8.2, J12.3, U1.4, U3.3

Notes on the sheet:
Line Power
Option: Relay Driver
Option: Status-LED
Option: User-Buttons
Option: I2C
Raspberry Pi
Power supply 9...24V
Option: Current Control
Option: NeoPixel
Power supply 5V
DC/DC Converter
Option: Power-relay, Aux-relay
H-Bridge

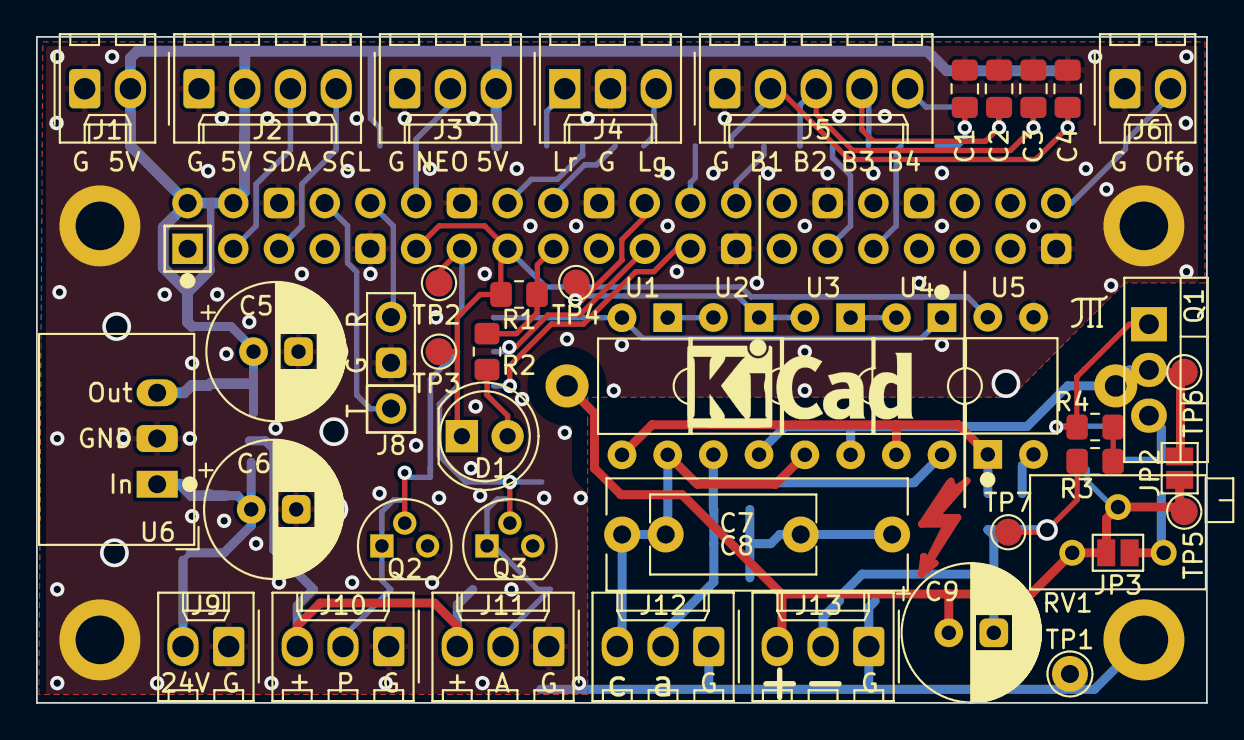
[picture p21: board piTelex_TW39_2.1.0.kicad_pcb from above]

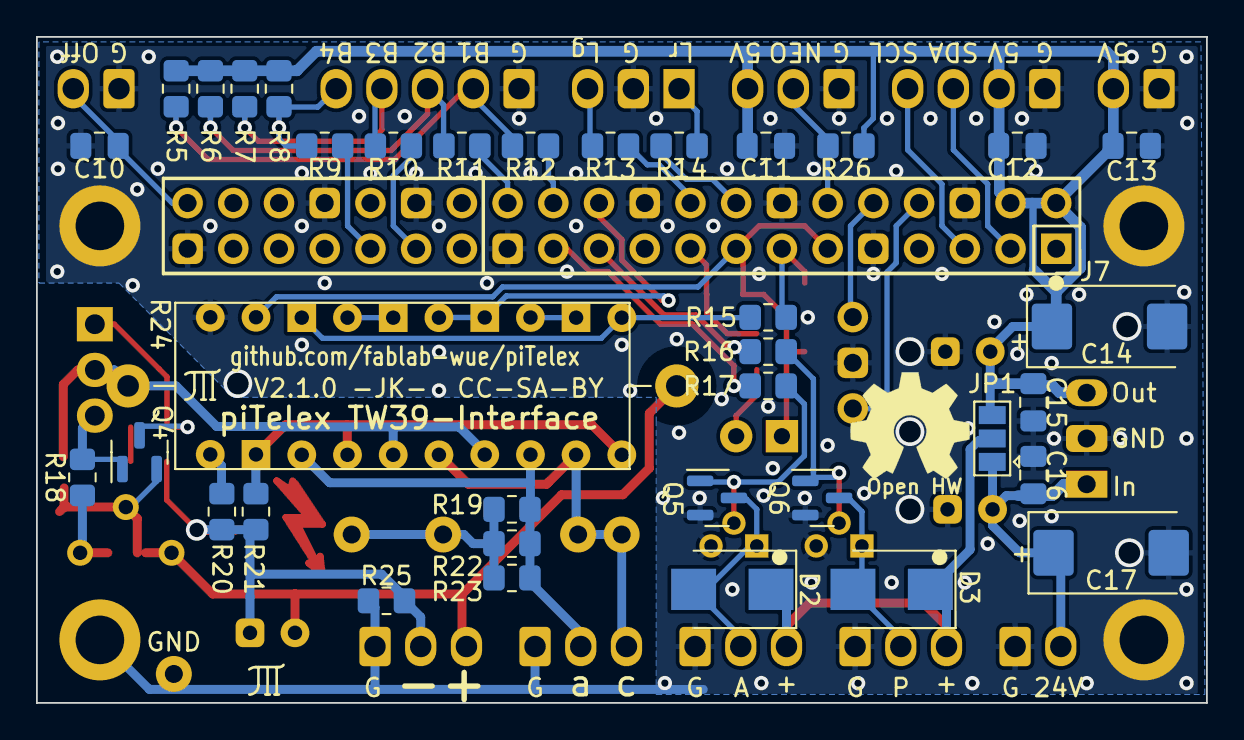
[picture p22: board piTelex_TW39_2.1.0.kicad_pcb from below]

Board: 2 copper layers, 65.0 x 37.0 mm, 88 parts (37 on the bottom side), 48 nets.

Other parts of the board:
KiCAD Logo: KiCad-Logo_5mm_SilkScreen
KiCAD Logo#2: Symbol_Highvoltage_Type1_CopperTop_Small

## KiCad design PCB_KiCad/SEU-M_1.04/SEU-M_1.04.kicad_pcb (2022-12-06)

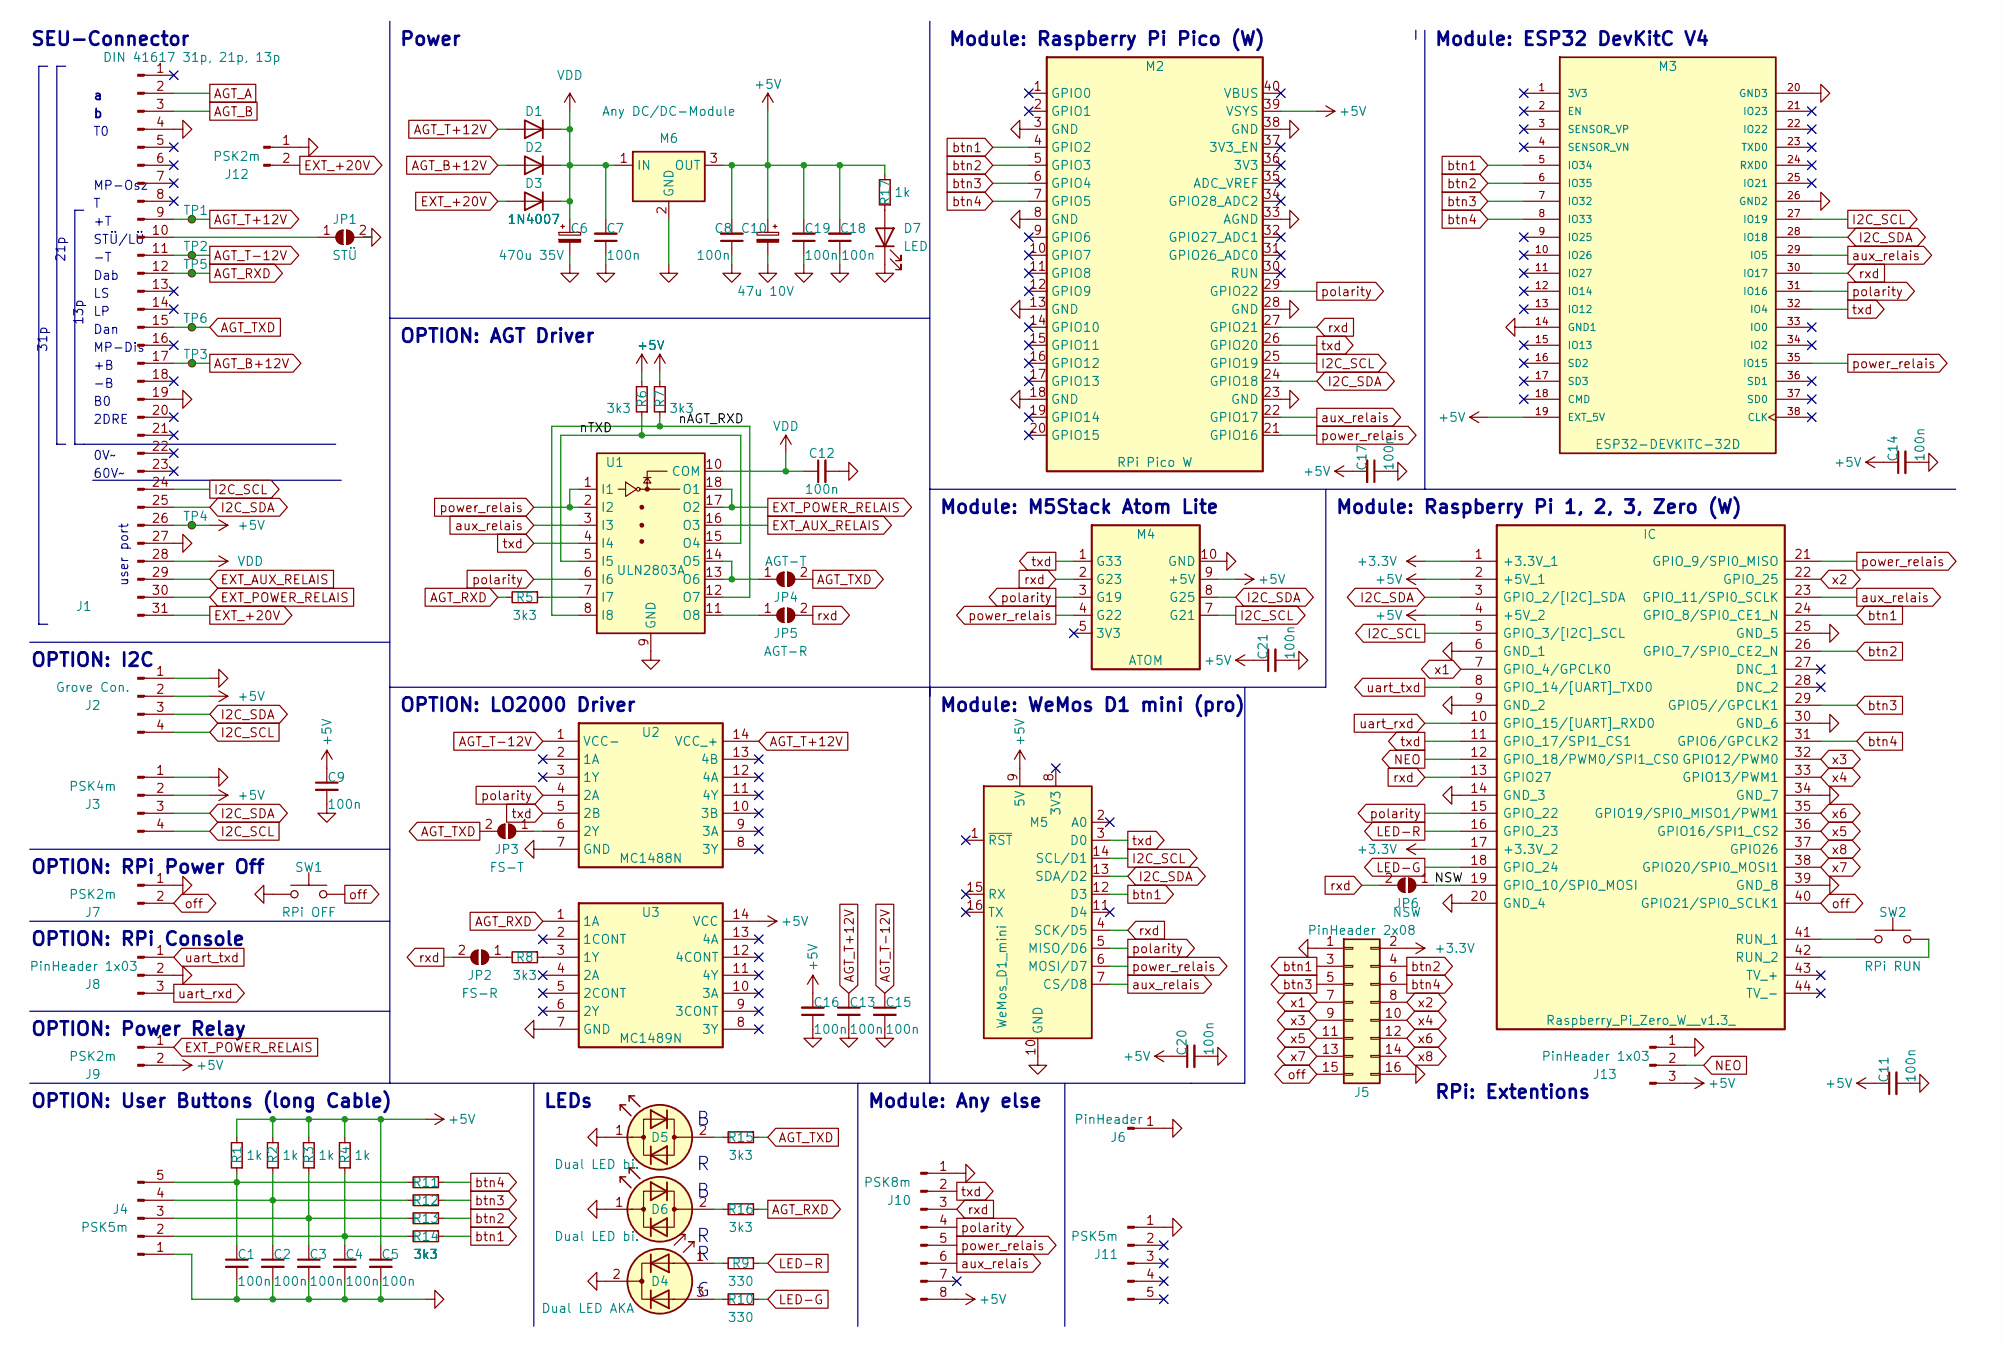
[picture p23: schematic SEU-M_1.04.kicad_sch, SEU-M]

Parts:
C1, C2, C3, C4, C5, C7, C8, C9, C11, C12, C13, C14, C15, C16, C17, C18, C19, C20, C21: 100n; C_Disc_D4.3mm_W1.9mm_P5.00mm
C6: 470u 35V; CP_Radial_D10.0mm_P2.50mm_P5.00mm
C10: 47u 10V; CP_Radial_D6.3mm_P2.50mm
D1, D2, D3: 1N4007; D_DO-41_SOD81_P10.16mm_Horizontal
D4: Dual LED AKA; LED_D3.0mm-3
D5, D6: Dual LED bi.; LED_D3.0mm
D7: LED; LED_D5.0mm
IC: Raspberry_Pi_Zero_W__v1.3_; RASPBERRYPIZEROWV13; Manufacturer_Part_Number Raspberry Pi Zero W (v1.3)
J1: DIN 41617 31p, 21p, 13p; DIN41617
J2: Grove Con.; JST_PH_B4B-PH-K_1x04_P2.00mm_Vertical
J3: PSK4m; Molex_KK-254_AE-6410-04A_1x04_P2.54mm_Vertical
J4, J11: PSK5m; Molex_KK-254_AE-6410-05A_1x05_P2.54mm_Vertical
J5: PinHeader 2x08; PinHeader_2x08_P2.54mm_Vertical
J6: PinHeader; PinHeader_1x01_P2.54mm_Vertical
J7, J9, J12: PSK2m; Molex_KK-254_AE-6410-02A_1x02_P2.54mm_Vertical
J8, J13: PinHeader 1x03; PinHeader_1x03_P2.54mm_Vertical
J10: PSK8m; Molex_KK-254_AE-6410-08A_1x08_P2.54mm_Vertical
JP1: STÜ; SolderJumper-2_P1.3mm_Open_RoundedPad1.0x1.5mm
JP2: FS-R; SolderJumper-2_P1.3mm_Open_RoundedPad1.0x1.5mm
JP3: FS-T; SolderJumper-2_P1.3mm_Open_RoundedPad1.0x1.5mm
JP4: AGT-T; SolderJumper-2_P1.3mm_Open_RoundedPad1.0x1.5mm
JP5: AGT-R; SolderJumper-2_P1.3mm_Open_RoundedPad1.0x1.5mm
JP6: NSW; SolderJumper-2_P1.3mm_Open_RoundedPad1.0x1.5mm
M2: RPi Pico W; RPi_Pico
M3: ESP32-DEVKITC-32D; MODULE_ESP32-DEVKITC-32D; PARTREV 4
M4: ATOM
M5: WeMos_D1_mini; WEMOS_D1_mini_light
M6: Any DC/DC-Module; DC_DC
R1, R2, R3, R4, R17: 1k; R_Axial_DIN0207_L6.3mm_D2.5mm_P10.16mm_Horizontal
R5, R6, R7, R8, R11, R12, R13, R14, R15, R16: 3k3; R_Axial_DIN0207_L6.3mm_D2.5mm_P10.16mm_Horizontal
R9, R10: 330; R_Axial_DIN0207_L6.3mm_D2.5mm_P10.16mm_Horizontal
SW1: RPi OFF; SW_PUSH_6mm
SW2: RPi RUN; SW_PUSH_6mm
TP1, TP2, TP3, TP4, TP5, TP6: TestPoint_Small; TestPoint_Pad_D1.5mm
U1: ULN2803A; DIP-18_W7.62mm
U2: MC1488N; DIP-14_W7.62mm
U3: MC1489N; DIP-14_W7.62mm

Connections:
+3.3V: IC.1 (+3.3V_1), IC.17 (+3.3V_2), J5.2
+5V: C5.1, C8.2, C9.1, C10.1, C11.1, C14.1, C16.2, C17.2, C18.2, C19.2, C20.1, C21.1, IC.2 (+5V_1), IC.4 (+5V_2), J1.26, J2.2, J3.2, J9.2, J10.8, J13.3, M2.39 (VSYS), M3.19 (EXT_5V), M4.9 (+5V), M5.9 (5V), M6.3 (OUT), R1.2, R2.2, R3.2, R4.2, R6.2, R7.2, R17.2, TP4.1, U3.14 (VCC)
/NSW: IC.19 (GPIO_10/SPI0_MOSI), JP6.1 (A)
/nAGT_RXD: R7.1, U1.8 (I8), U1.12 (O7)
/nTXD: R6.1, U1.5 (I5), U1.15 (O4)
AGT_A: J1.2
AGT_B: J1.3
AGT_B+12V: D2.2 (A), J1.17, TP3.1
AGT_RXD: J1.12, R5.2, R16.1, TP5.1, U3.1 (1A)
AGT_T+12V: C13.1, D1.2 (A), J1.9, TP1.1, U2.14 (VCC_+)
AGT_T-12V: C15.1, J1.11, TP2.1, U2.1 (VCC-)
AGT_TXD: J1.15, JP3.2 (B), JP4.2 (B), R15.1, TP6.1
EXT_+20V: D3.2 (A), J1.31, J12.2
EXT_AUX_RELAIS: J1.29, U1.16 (O3)
EXT_POWER_RELAIS: J1.30, J9.1, U1.17 (O2), U1.18 (O1)
GND: C1.2, C2.2, C3.2, C4.2, C5.2, C6.2, C7.1, C8.1, C9.2, C10.2, C11.2, C12.2, C13.2, C14.2, C15.2, C16.1, C17.1, C18.1, C19.1, C20.2, C21.2, D4.2 (K), D5.1 (KA), D6.1 (KA), D7.1 (K), IC.6 (GND_1), IC.9 (GND_2), IC.14 (GND_3), IC.20 (GND_4), IC.25 (GND_5), IC.30 (GND_6), IC.34 (GND_7), IC.39 (GND_8), J1.4, J1.19, J1.27, J2.1, J3.1, J4.1, J5.1, J5.16, J6.1, J7.1, J8.2, J10.1, J11.1, J12.1, J13.1, JP1.2 (B), M2.3 (GND), M2.8 (GND), M2.13 (GND), M2.18 (GND), M2.23 (GND), M2.28 (GND), M2.33 (AGND), M2.38 (GND), M3.14 (GND1), M3.20 (GND3), M3.26 (GND2), M4.10 (GND), M5.10 (GND), M6.2 (GND), SW1.1, U1.9 (GND), U2.7 (GND), U3.7 (GND)
I2C_SCL: IC.5 (GPIO_3/[I2C]_SCL), J1.24, J2.4, J3.4, M2.25 (GPIO19), M3.27 (IO19), M4.7 (G21), M5.14 (SCL/D1)
I2C_SDA: IC.3 (GPIO_2/[I2C]_SDA), J1.25, J2.3, J3.3, M2.24 (GPIO18), M3.28 (IO18), M4.8 (G25), M5.13 (SDA/D2)
LED-G: IC.18 (GPIO_24), R10.1
LED-R: IC.16 (GPIO_23), R9.1
NEO: IC.12 (GPIO_18/PWM0/SPI1_CS0), J13.2
unnamed: C1.1, J4.5, R1.1, R11.2
unnamed: C2.1, J4.4, R2.1, R12.2
unnamed: C3.1, J4.3, R3.1, R13.2
unnamed: C4.1, J4.2, R4.1, R14.2
unnamed: D4.1 (A1), R9.2
unnamed: D4.3 (A2), R10.2
unnamed: D5.2 (AK), R15.2
unnamed: D6.2 (AK), R16.2
unnamed: D7.2 (A), R17.1
unnamed: J1.10, JP1.1 (A)
unnamed: JP2.1 (A), R8.2
unnamed: JP3.1 (A), U2.6 (2Y)
unnamed: JP4.1 (A), U1.13 (O6), U1.14 (O5)
unnamed: JP5.1 (A), U1.11 (O8)
unnamed: IC.41 (RUN_1), SW2.1
unnamed: IC.42 (RUN_2), SW2.2
unnamed: R5.1, U1.7 (I7)
unnamed: R8.1, U3.3 (1Y)
VDD: C6.1, C7.2, C12.1, D1.1 (K), D2.1 (K), D3.1 (K), J1.28, M6.1 (IN), U1.10 (COM)
aux_relais: IC.23 (GPIO_11/SPI0_SCLK), J10.6, M2.22 (GPIO17), M3.29 (IO5), M5.7 (CS/D8), U1.3 (I3)
btn1: IC.24 (GPIO_8/SPI0_CE1_N), J5.3, M2.4 (GPIO2), M3.5 (IO34), M5.12 (D3), R14.1
btn2: IC.26 (GPIO_7/SPI0_CE2_N), J5.4, M2.5 (GPIO3), M3.6 (IO35), R13.1
btn3: IC.29 (GPIO5//GPCLK1), J5.5, M2.6 (GPIO4), M3.7 (IO32), R12.1
btn4: IC.31 (GPIO6/GPCLK2), J5.6, M2.7 (GPIO5), M3.8 (IO33), R11.1
off: IC.40 (GPIO21/SPI0_SCLK1), J5.15, J7.2, SW1.2
polarity: IC.15 (GPIO_22), J10.4, M2.29 (GPIO22), M3.31 (IO16), M4.3 (G19), M5.5 (MISO/D6), U1.6 (I6), U2.4 (2A)
power_relais: IC.21 (GPIO_9/SPI0_MISO), J10.5, M2.21 (GPIO16), M3.35 (IO15), M4.4 (G22), M5.6 (MOSI/D7), U1.1 (I1), U1.2 (I2)
rxd: IC.13 (GPIO27), J10.3, JP2.2 (B), JP5.2 (B), JP6.2 (B), M2.27 (GPIO21), M3.30 (IO17), M4.2 (G23), M5.4 (SCK/D5)
txd: IC.11 (GPIO_17/SPI1_CS1), J10.2, M2.26 (GPIO20), M3.32 (IO4), M4.1 (G33), M5.3 (D0), U1.4 (I4), U2.5 (2B)
uart_rxd: IC.10 (GPIO_15/[UART]_RXD0), J8.3
uart_txd: IC.8 (GPIO_14/[UART]_TXD0), J8.1
x1: IC.7 (GPIO_4/GPCLK0), J5.7
x2: IC.22 (GPIO_25), J5.8
x3: IC.32 (GPIO12/PWM0), J5.9
x4: IC.33 (GPIO13/PWM1), J5.10
x5: IC.36 (GPIO16/SPI1_CS2), J5.11
x6: IC.35 (GPIO19/SPI0_MISO1/PWM1), J5.12
x7: IC.38 (GPIO20/SPI0_MOSI1), J5.13
x8: IC.37 (GPIO26), J5.14

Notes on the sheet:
13p
Dan
OPTION: Power Relay
31p
OPTION: LO2000 Driver
STÜ/LÜ
Module: M5Stack Atom Lite
Module: WeMos D1 mini (pro)
user port
Module: Any else
OPTION: I2C
0V~
SEU-Connector
60V~
Module: ESP32 DevKitC V4
Dab
LEDs
2DRE
OPTION: RPi Console
Power
OPTION: User Buttons (long Cable)
Module: Raspberry Pi Pico (W)
RPi: Extentions
MP-Dis
OPTION: AGT Driver
21p
Module: Raspberry Pi 1, 2, 3, Zero (W)
MP-Osz
OPTION: RPi Power Off

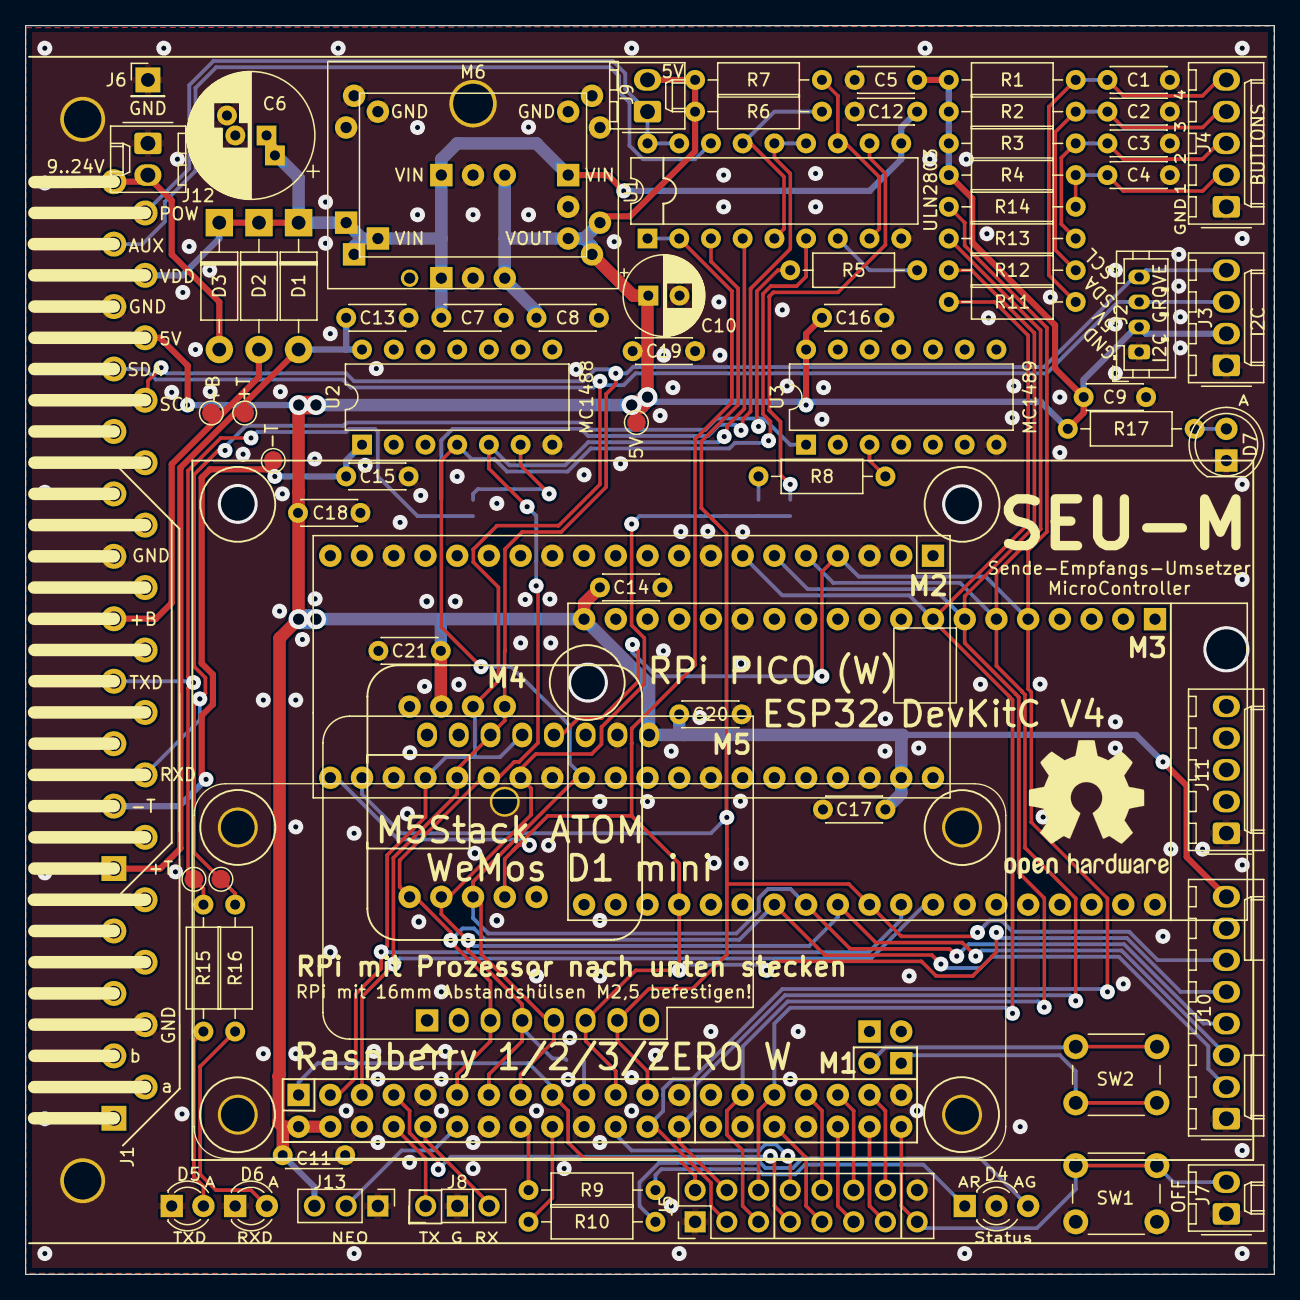
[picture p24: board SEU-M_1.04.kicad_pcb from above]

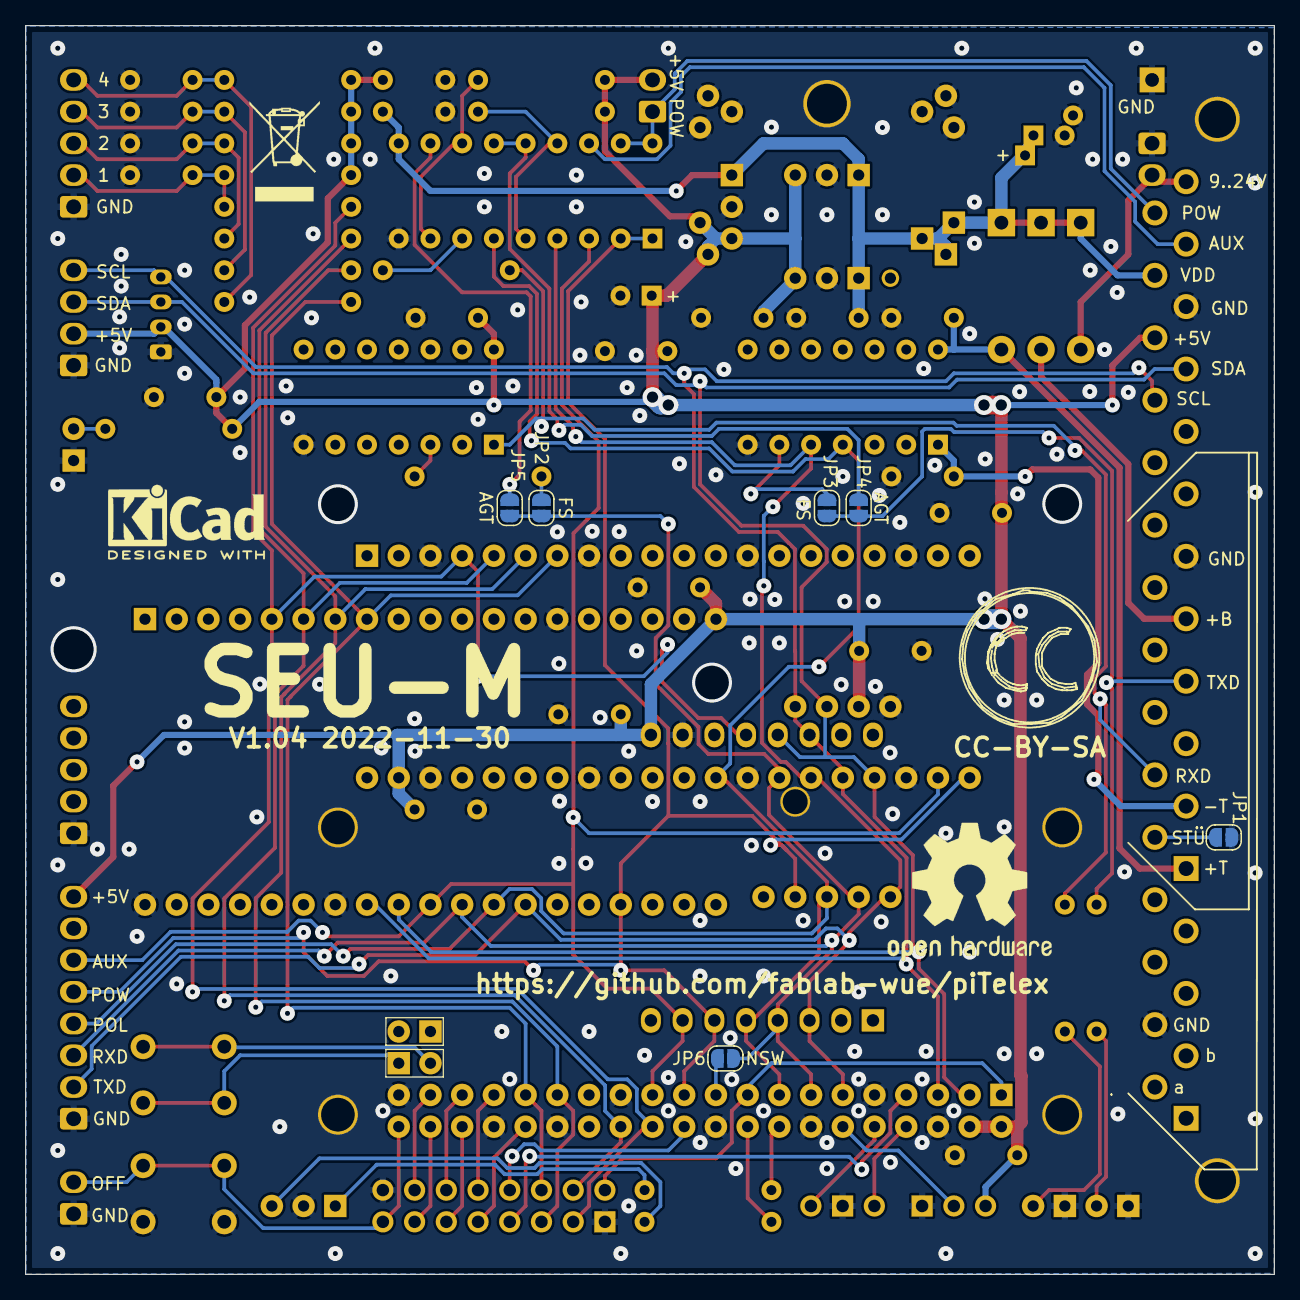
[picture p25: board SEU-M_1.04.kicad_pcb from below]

Board: 2 copper layers, 100.0 x 100.0 mm, 81 parts (7 on the bottom side), 58 nets.

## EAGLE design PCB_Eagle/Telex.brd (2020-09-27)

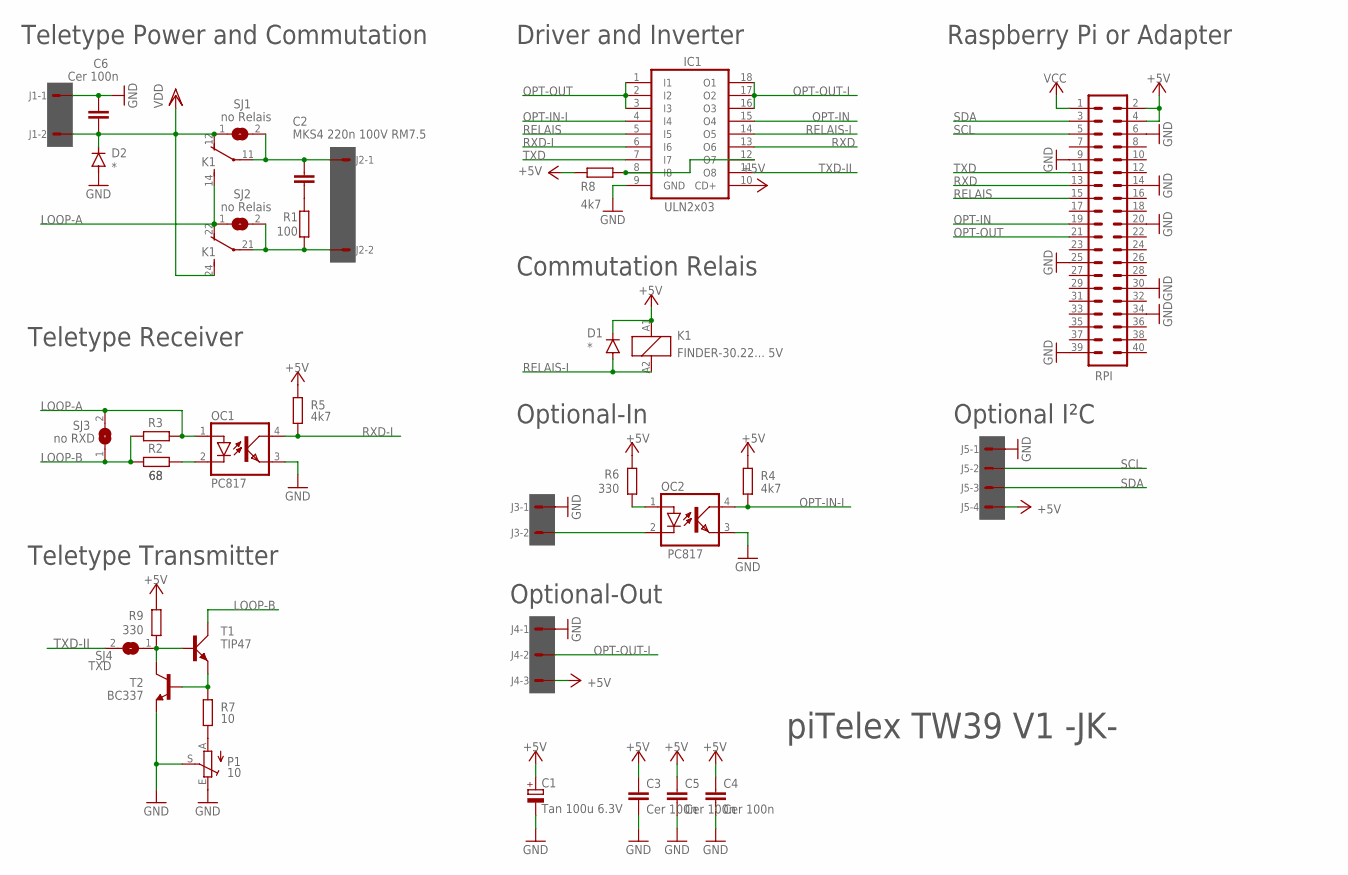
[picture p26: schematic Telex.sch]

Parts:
C1: Tan 100u 6.3V; E2,5-6
C2: MKS4 220n 100V RM7.5; C075-042X103
C3, C4, C5, C6: Cer 100n; C050-024X044
D1, D2: *; MINIMELF
IC1: ULN2x03; DIL18
J1, J2, J3: 22-27-2021-02; 6410-02
J4: 22-27-2031-03; 6410-03
J5: 22-27-2041-04; 6410-04
K1: FINDER-30.22... 5V; FINDER-30.22
OC1, OC2: PC817; DIL04
P1: 10; S64Y
R1: 100; 0204/7
R2, R3: 68; 0204/7
R4, R5, R8: 4k7; 0204/7
R6, R9: 330; 0204/7
R7: 10; 0204/7
RPI: MA20-2
SJ1, SJ2: no Relais; SJ
SJ3: no RXD; SJ
SJ4: TXD; SJ
T1: TIP47; TO220AV
T2: BC337; TO92

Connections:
+5V: C1.+, C3.1, C4.1, C5.1, D1.C, IC1.10 (CD+), J4.3, J5.4, K1.A1 (1), R4.1, R5.1, R6.2, R8.1, R9.1, RPI.2, RPI.4
GND: C1.-, C3.2, C4.2, C5.2, C6.2, D2.A, IC1.9 (GND), J1.1, J3.1, J4.1, J5.1, OC1.3 (EMIT), OC2.3 (EMIT), P1.E, P1.S, RPI.6, RPI.9, RPI.14, RPI.20, RPI.25, RPI.30, RPI.34, RPI.39, T2.1 (E)
LOOP-A: K1.14 (S), K1.22 (O), OC1.1 (A), R3.1, SJ2.1, SJ3.2
LOOP-B: R2.2, R3.2, SJ3.1, T1.C
unnamed: C2.2, R1.2
unnamed: OC1.2 (C), R2.1
unnamed: OC2.1 (A), R6.1
unnamed: C2.1, J2.1, K1.11, SJ1.2
unnamed: P1.A, R7.1
unnamed: J2.2, K1.21, R1.1, SJ2.2
unnamed: J3.2, OC2.2 (C)
unnamed: R7.2, T1.E, T2.2 (B)
OPT-IN: IC1.15 (O4), RPI.19
OPT-IN-I: IC1.4 (I4), OC2.4 (COL), R4.2
OPT-OUT: IC1.1 (I1), IC1.2 (I2), IC1.3 (I3), RPI.21
OPT-OUT-I: IC1.16 (O3), IC1.17 (O2), IC1.18 (O1), J4.2
RELAIS: IC1.5 (I5), RPI.15
RELAIS-I: D1.A, IC1.14 (O5), K1.A2 (2)
RXD: IC1.13 (O6), RPI.13
RXD-I: IC1.6 (I6), OC1.4 (COL), R5.2
SCL: J5.2, RPI.5
SDA: J5.3, RPI.3
TXD: IC1.7 (I7), RPI.11
TXD-II: IC1.11 (O8), SJ4.2
TXD-IIX: R9.2, SJ4.1, T1.B, T2.3 (C)
TXT-I: IC1.8 (I8), IC1.12 (O7), R8.2
VCC: RPI.1
VDD: C6.1, D2.C, J1.2, K1.12 (O), K1.24 (S), SJ1.1

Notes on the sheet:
piTelex TW39 V1 -JK-
Optional-Out
Optional-In
Commutation Relais
Driver and Inverter
Raspberry Pi or Adapter
Teletype Power and Commutation
Teletype Receiver
Teletype Transmitter
Optional I²C

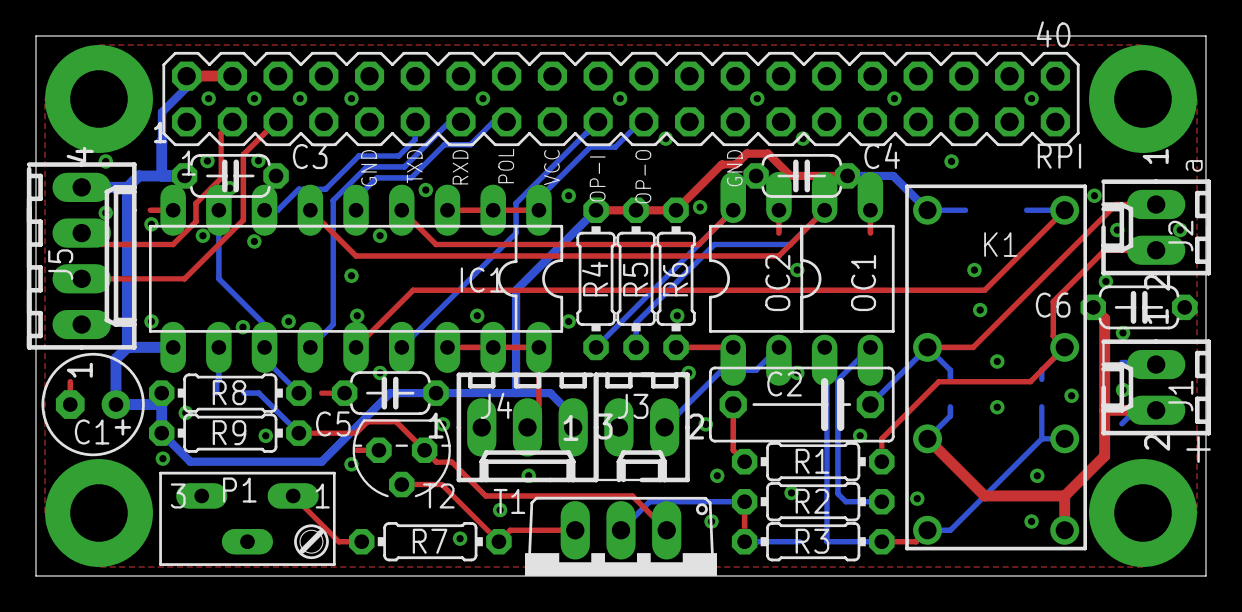
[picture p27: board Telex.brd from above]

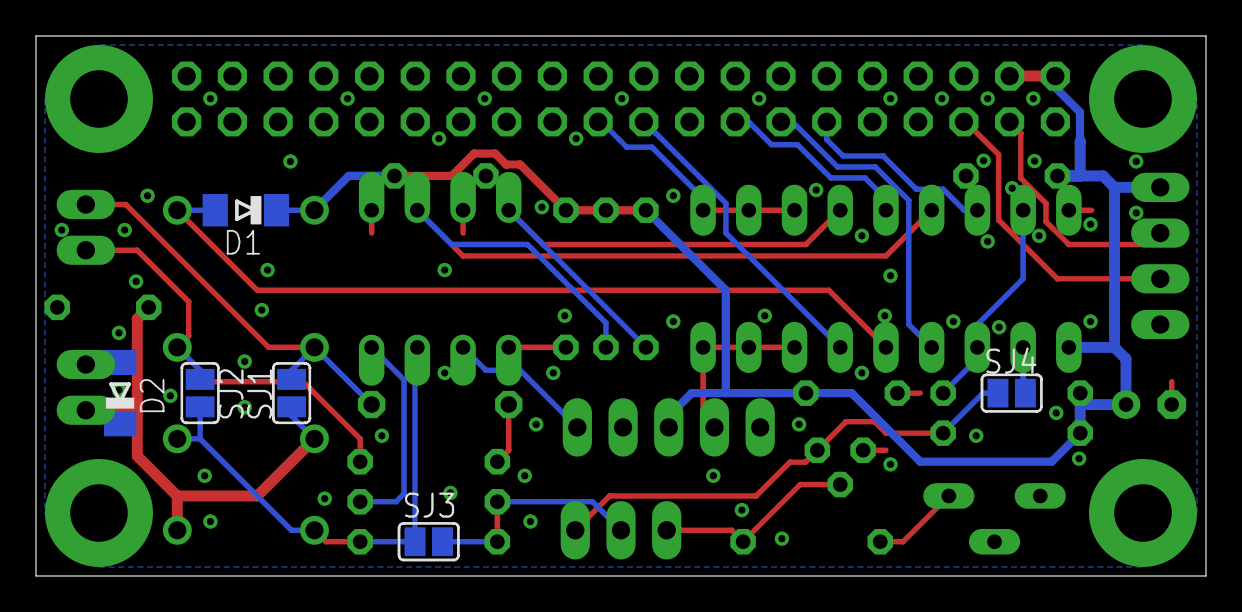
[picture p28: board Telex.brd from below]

Board: 2 copper layers, 65.0 x 30.0 mm, 34 parts (6 on the bottom side), 27 nets.

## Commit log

2020-09-27 moved files from main project
    [CCITT-2.xlsx, Historie.xlsx, Telex.brd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]
2022-12-06 Added PCB SEU-M_1.04
    [SEU-M_1.04-B_Cu.gbr, SEU-M_1.04-B_Mask.gbr, SEU-M_1.04-B_Silkscreen.gbr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]
2023-02-16 added PCB piTelex_TW39_2.1.0
    [piTelex_TW39_2.1.0-B_Cu.gbr, piTelex_TW39_2.1.0-B_Mask.gbr, piTelex_TW39_2.1.0-B_Silkscreen.gbr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]
2023-02-16 added PCB piTelex_V10_1.0.0
    [piTelex_V10_1.0.0-B_Cu.gbr, piTelex_V10_1.0.0-B_Mask.gbr, piTelex_V10_1.0.0-B_Silkscreen.gbr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]

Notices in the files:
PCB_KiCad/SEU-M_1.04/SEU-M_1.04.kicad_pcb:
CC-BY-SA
